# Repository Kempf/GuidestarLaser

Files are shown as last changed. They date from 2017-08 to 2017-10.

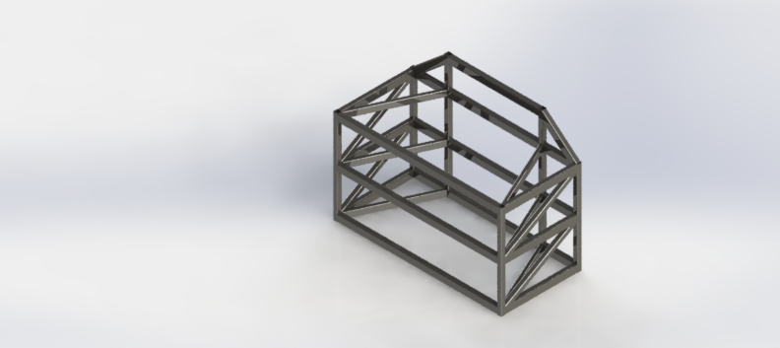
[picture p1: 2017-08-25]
Working_Files/Figures/3_tier_concept_1.JPG

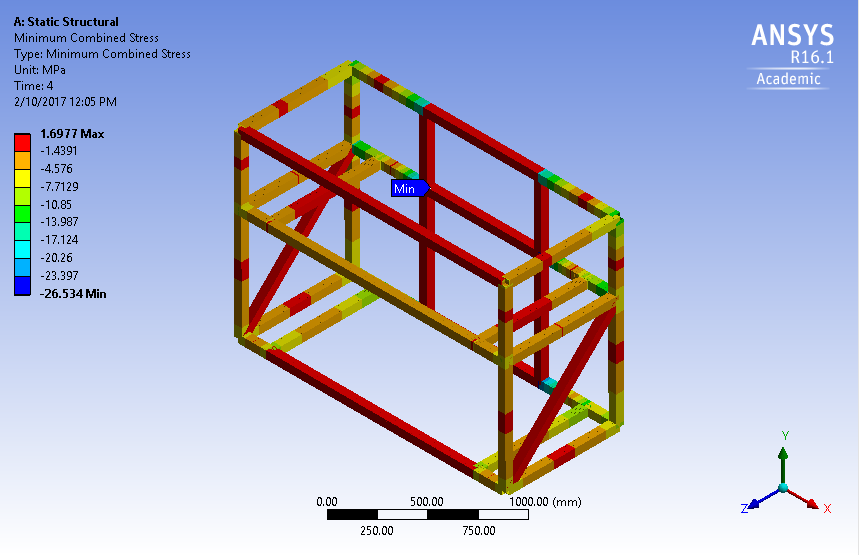
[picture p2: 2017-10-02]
Working_Files/Mechanical_Interface_Preliminary_Design/ansys_analysis/figures/min_comb_stress.PNG

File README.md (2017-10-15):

# Guide Star Laser Project

Repository created on: 04/08/2017

The goal of the project is to develop a **preliminary design** for mounting the EOS and ANU guide star lasers on the EOS 1.8m telescope at Mt. Stromlo, including a document detailing the full requirements and specifications with the highest level of precision available 
with the information avaiable for the most likely configurations, and CAD models supporting this information.

The telescope is used for **laser-tracking satellites** and **space debris**, but its accuracy is limited by the **atmospheric distortions**. A laser guide star (produced by a **guide star laser**, which excites the sodium layer in the atmosphere)
can be used to correct the atmospheric distortions using **adaptive optics** on the telescope. Two such guide star lasers (GSLs) are currently being made for the telescope.

The key components of the mounting are the **mechanical interface** (the support frame and actual physical mounting technique, including vibration limiting techniques), the **environmental
considerations** such as air quality and humidity limitations, the **electrical and communication** limitations involved with mounting the lasers and connecting them to the control system,
due to limitations in the available connections within the dome, and the **logistical concerns**, due to the difficulty of mounting a large laser into the dome, which is a confined space. 

The team works on this **weekly** on Fridays 9-5 in a shared space at AITC, Mt Stromlo, enabling strong communication within the team, as well as ease of communications with our client and stakeholders. 
Additional work is completed externally, including meetings for feedback reviews and individual work.

project diagram

(Diagram supplied by EOS)

## Team

| Member Name  	| UID | Responsibilities | Skills 	|
|---	|---	|---	|---|
| Alex Dalton  	|  u5889439 | Project Manager, Mech., CAD |Mechanical/Materials Eng, CAD, Project management
| Brian Ma  	|  u5893274 | Electrical |Power electronics/system Eng, MATLAB, Python, embeded C, microprocessor, wirless communication |
| Chris Leow  	|  u5827718 | Minutes, Design Report |Mechanical/Materials Eng, Fluid Mechanics & Heat Transfer, Project management, secretary experience, technical dawing|
| Paul Apelt  	|  u5568225 | Project requirements |Electronic/Mechatronic, MATLAB, Python |
| Steve Lonergan|  u5349877 | Point of Contact, vibration|Electronic/Mechatronic, MATLAB, Project Management|
| Wenjie Mu  	|  u5354143 | Cooling |Mechatronics/Renewable Systems, MATLAB, Hardware Programming |
*"Responsibilities" are the areas for which the team member is the key source of knowledge.
All team members will contribute to related project tasks as required.

## Information for Auditors

The readmes of the higher level directories detail their contents, to aid in finding the relevant files and information. 

In this audit cycle, we have completed the seecond, and majority of the third phase of our project - this has been completion of concept designs for each of the Environmental, Mechanical, and Electrical work packages. This is shown in 
the reports for each section. We have also further updated the system subsystem requirements to reflect the current state of the project. The handover document, as well as the Concept Design Report, are still to be completed, however these are 
summaries of the work package reports.

Significant additional information became available in this time period due to the contract on the laser being arranged, however there are still gaps in this information which will be tasked to the next project team.

To get an understanding of what the most relevant files are for this (2nd) audit, go to:
[Current Status Directory](https://gitlab.cecs.anu.edu.au/u5568225/GuidestarLaser/tree/master/Current_Status) 
and read the **Weekly_And_Audit_Summaries.pdf** file.  This will guide you through where to go, what to look at, and what they are.

## Contents

* **Client Communications**: contains all one-way communication with the client, 
including **emails** and **information provided**. This does not include the transcripts
of meetings held with the client present, which are instead in the 
"Meeting Minutes".

* **Current Status**: contains key documents showing the current status of the
project; the **calendar** shows key upcoming dates, while the currrent work 
section contains a statement of the things that need to be done and areas of
priority up until the next update. Periodically updated as work progresses.
	
* **Meeting Minutes**: contains **minutes** for group meetings,
tutorials, and client meetings.

* **Previous Team Work**: this directory effectively contains the entirety of the
**previous group's repository** on this project, to be used as reference material
for our continuation of their work. The readme file within this repository
contains the contents and breakdown, in order to avoid oversaturating this file.

* **Project Deliverables**: contains final project outputs, concept and subsystem design reports.

* **Working Files**: this directory contains **techincal project documents**, **requirements** and
deliverables. Confidential documents are not available for viewing, however
a brief description is provided in the readme file.

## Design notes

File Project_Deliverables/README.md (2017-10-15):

## Project Deliverables
Final project outputs

### Directories
*   **CAD**: contains solidworks laser enclosure models.
### Files

*	`ProForma_Ver005.pdf`:	[Overleaf](https://www.overleaf.com/10595988ydvxrwtmksfk) Initial project document, giving project outline, status, and risks associated with it.
*	`CoDR.pdf`:	Final summary document that summarieses all work packages, and the project as a whole. Overleaf: https://www.overleaf.com/read/mfkmyykbmsgq
*	`Electrical_Subsystem_Design.pdf`:	Design report of the electrical system. Overleaf: https://www.overleaf.com/read/cgpdrtmwvhnf
*	`Environmental_Subsystem_Design.pdf`:	Design report of the environmental system. Overleaf: https://www.overleaf.com/read/kgrchxybbxrv
*	`Mechanical_Subsystem_Design.pdf`:	Design report of the mechanical system. Overleaf: https://www.overleaf.com/read/rwhvbqhndjvv
*   `Updated_System_Subsystem_Specifications_Verxxx`: contains system requirements.
*   `Handover_Document.pdf`: contains information for the next team.

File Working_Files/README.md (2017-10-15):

## Working Files
This folder is the general folder for storage of files and work completed.

### Directories
*	**Audit_Feedback_Actions**: Actions and decisions made in response to client and shadow feedback.
*	**Cable_Routing**: diagrams with measurments of cable trays.
*	**Concept_Design_Report_Documentation**: contains the concept design report.
*	**Dome_Photos**: photos of the telescope space.
*	**Electrical_Interface_Preliminary_Design**: electrical schematics and considerations.
*	**Environmental_Interface_Preliminary_Design**: environmental schematics and considerations.
*	**Figures**: generic figures for reports, diagrams, etc.
*	**Liquid Cooling**:	Cooling schematics folder
*	**Mechanical_Interface_Preliminary_Design**: CAD frame design and ANSYS analysis
*	**Outdated**: contains old versions of documents.
*	**Poster**:	Contains the poster for submission

### Files
*	`Work_Ethic_Agreement.docx`:	This file details the expectations that the group has for each group member, regarding weekly workload and work locations, as well as communications standards, and expectations in the event of absences.
	
*	`ProForma_Verxxx.pdf`:		Details the scope of the project, the project objectives and deliverables, as well as a basic scheduling, project breakdown, and risk analysis. This is intended as an update of the previous teams work, as well as an overview of the project. Overleaf: https://www.overleaf.com/10595988ydvxrwtmksfk#/39637919/
	
*	`Clean_System_Subsystem_Requirements_Updated_Ver001`:      Updated System Requirements Document. Cleaned of old requirements. Overleaf:  https://www.overleaf.com/10750310ksnspqwxvswk  Work-In-Progress

*	`Trace_System_Subsystem_Requirements_Updated_Ver001`:      Updated System Requirements Document. Build off System_Subsystem_Requirements. Overleaf:  https://www.overleaf.com/11432648vkzvdvqvqdgp  Work-In-Progress

*	`System_Subsystem_Requirements.pdf`:     System Subsystem Specifications - from previous team work

*	`DRAFT_laser_mounting_concepts.pdf`:     Details the different scenarios for the laser mounting order / structure

*	[Conflict resolution](https://docs.google.com/document/d/17XI3bLXP9oA0JVAiUGPcVCycXSnSJn45uxt__P4Jb6M/edit?usp=sharing) -  TODO list to resolve requirement conflicts

*	[Vibration Overview](https://docs.google.com/document/d/1Qyyc3R13YdVeQmGfrSNuc1xS96W7sWySw377b-xw7Hk/edit?usp=sharing) - google doc with information on vibration-sensitive components.

*	[Concept Design Report](https://www.overleaf.com/10956191yqmndhrgpfbn) (overleaf draft)

*	[Electrical Subsystem Design](https://www.overleaf.com/11322851qgcphdpmpbkq) (overleaf)

*	[Environmental Subsystem Design](https://www.overleaf.com/11303618bsgxdkttkfjt) (overleaf)

*	[Mechanical Subsystem Design](https://www.overleaf.com/11387889gsdtxpvjycmr) (overleaf)

*	[Audit Presentation](https://docs.google.com/presentation/d/1nnK7gd8TsdCD4ll5tbwI-uf9ibSjlfKKlfrT97bMyMw/edit?usp=sharing) - on google docs

*	[Client & JW meeting presentation](https://docs.google.com/presentation/d/1jMZxCukPx--ZBQRgz2PcXL9bV2g-9_YzMjzdAsr_qN8/edit?usp=sharing) - google docs draft

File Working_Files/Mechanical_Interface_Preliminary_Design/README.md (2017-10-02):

### Directories
*	**ansys_analysis**: files relating to ANSYS analysis of the mounting frame
*	**solidworks_models**: files relating to SolidWorks modelling of the mounting frame

### Files
*	**Breadboard_DataSheet.pdf**: scanned copy of the Carbon Figure breadboard specifications
*	**README.md**: this file

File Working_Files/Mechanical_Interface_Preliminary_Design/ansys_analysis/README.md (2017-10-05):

### Directories
*	**figures**: ANSYS screenshots to present in subsystem report

### Files
*	**1D_frame_model.agdb**: ANSYS geometry file for 1D frame model
*   **frame_analysis.mechdat**: ANSYS analysis file
*   **material_data.xml**: Material constants for isotropic approximation of carbon fibre/epoxy composite
*	**README.md**: this file

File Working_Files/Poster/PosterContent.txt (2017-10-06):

Project Summary

A Guide Star Laser (GSL) creates an artificial star in the atmosphere known as a Laser Guide Star (LGS), which enables the measurement of light distortion caused by atmospheric turbulance. Adaptive Optics (AO) systems use these measurements to correct for this distortion and improve imaging quality.
The ANU and Electric-Optic Systems (EOS) are currently designing two GSL systems for Space Debris Tracking and Pushing. The objective of this project was to develop the concept design for the system interface with the 1.8m telescope at Mount Stromlo. This is the second phase of this student led project, with the first phase involving the development of a comprehensive requirements document.

Laser Enclosure
[IMAGE Frame]
A frame was designed to mount the GSL Laser Heads to the 1.8m telescope. The frame accomodates two optical breadboards and is constructed from DragonPlate Carbon Fibre/Epoxy components, steel inserts and various fasteners.
Insulation panelling and radiators are used to ensure the enclosure temperature remains within tolerable limits. A closed air circulation and filtration system is used to keep air quality to the required ISO 7 Standard. 

ANU Aux EC
The ANU laser power draw requirements are still unknown as the vendor agreement was recently signed, but it will require less than 800W of cooling and 1 CAN bus to monitor and control the status. The electrical cabinet will require one main power socket and the possibility of an additional cooler and power socket that has yet to be finalised. 

[IMAGE]
The ANU GSL has vibrationally sensitive components that will be dampened, while the EOS GSL will be require further analysis as coolers and fans may disrupt instrumentation alignment on breadboards. 

EOS Oscillators
The EOS Oscillators are sensitive to vibrations and have been relocated to an external clean room. This requires additional wiring to connect the oscillators to the observation level. 

EOS Aux EC
The EOS GSL requires a standard power socket to provide 2.4kW of power single phase controlled using a CAN bus and an ethernet cable for maintenance. The heat exchangers will require 3 main power sockets and 1 for the chiller that will provide approximately 400W of water cooling. The EOS GSL requires a minimum of 10 power cables that enter the breadboard for coolers, heat exchangers and providing power.

Summary
Review and additional development of the interface requirements was undertaken by the team. Conceptual designs for the various subsystems were then developed. The designs and recommendations were provided to the client in a Concept Design Report and Subsystem Design Reports. The next phase of the project will involve the development of detailed designs. The team will produce a handover document that introduces the new team to project and outlines the recommended next steps.

Acknowledgements
James Webb, Mark Blundell, Celine d’Orgeville, Jordan Davis, Gerrard Kennedy and all others at ANU, AITC and EOS who made this project possible.

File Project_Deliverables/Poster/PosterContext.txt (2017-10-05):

Project Summary
This iteration of the project utilises design requirements from the previous group to synthesis a concept design for a system interface that is capable of accommodating two Guide Star Laser (GSL) solutions for a 1.8m telescope. A GSL creates an artificial star known as a Laser Guide Star (LGS) in the atmosphere that enables the measurement of phase distortions caused by atmospheric turbulence. Thus, an Adaptive Optics (AO) system for satellite Imaging (AOI) and space debris Tracking and Pushing is enabled (AOTP). 
Laser Enclosure
[IMAGE Frame]
The quasi-isotropic carbon fibre/epoxy composite frame is designed to accommodate two breadboards using square hollow section members and prefabricated gusset plates from DragonPlate an American manufacturer. By utilising carbon fibre, it reduces the mass of the structure while also the Coefficient of Thermal Expansion (CTE) in comparison to steel, that would otherwise affect the alignment of instrumentation on the breadboards during extreme temperature changes the telescope is exposed to. Removable opaque panelling made of ?? will be placed on the sides of the frame to adhere to laser safety, while also reducing dust particulates settling on the breadboards. 
ANU Aux EC

Logistics
There is not enough information 
Wiring (vibration + environment)
Air quality within the enclosure is required to be ISO 7 standard, and temperature must be regulated to enable the temperature range to remain between 5℃-30℃. A closed air circulating system to filter air and cool enclosure air. 
[IMAGE]
The ANU GSL has vibrationally sensitive components that will be dampened, while the EOS GSL will be require further analysis as coolers and fans may disrupt instrumentation alignment on breadboards. 
EOS Oscillators
The Electro-Optic Systems (EOS) Oscillators and vibrationally sensitive and therefore have been relocated to the clean room, resulting in the need for wiring to run from the clean room to the observation deck in the telescope. 
EOS Aux EC

Acknowledgements
James Webb, Mark Blundell, Celine d’Orgeville, Jordan Davis

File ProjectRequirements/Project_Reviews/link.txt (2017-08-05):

https://drive.google.com/open?id=0B3XSOOtE5u1ubnV5ZG04RnpfVTQ
Link to google drive hosting the powerpoints

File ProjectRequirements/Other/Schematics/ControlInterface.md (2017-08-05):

%!PS-Adobe-3.0 EPSF-3.0
%%Creator: Mayura Draw, Version 4.5
%%Title: ControlInterface.md
%%CreationDate: Wed Apr 05 11:33:21 2017
%%BoundingBox: 20 26 591 784
%%DocumentFonts: ArialMT
%%Orientation: Landscape
%%EndComments
%%BeginProlog
%%BeginResource: procset MayuraDraw_ops
%%Version: 4.5
%%Copyright: (c) 1993-2003 Mayura Software
/PDXDict 100 dict def
PDXDict begin
% width height matrix proc key cache
% definepattern -\> font
/definepattern { %def
  7 dict begin
    /FontDict 9 dict def
    FontDict begin
      /cache exch def
      /key exch def
      /proc exch cvx def
      /mtx exch matrix invertmatrix def
      /height exch def
      /width exch def
      /ctm matrix currentmatrix def
      /ptm matrix identmatrix def
      /str
      (xxxxxxxxxxxxxxxxxxxxxxxxxxxxxxxx)
      def
    end
    /FontBBox [ %def
      0 0 FontDict /width get
      FontDict /height get
    ] def
    /FontMatrix FontDict /mtx get def
    /Encoding StandardEncoding def
    /FontType 3 def
    /BuildChar { %def
      pop begin
      FontDict begin
        width 0 cache { %ifelse
          0 0 width height setcachedevice
        }{ %else
          setcharwidth
        } ifelse
        0 0 moveto width 0 lineto
        width height lineto 0 height lineto
        closepath clip newpath
        gsave proc grestore
      end end
    } def
    FontDict /key get currentdict definefont
  end
} bind def

% dict patternpath -
% dict matrix patternpath -
/patternpath { %def
  dup type /dicttype eq { %ifelse
    begin FontDict /ctm get setmatrix
  }{ %else
    exch begin FontDict /ctm get setmatrix
    concat
  } ifelse
  currentdict setfont
  FontDict begin
    FontMatrix concat
    width 0 dtransform
    round width div exch round width div exch
    0 height dtransform
    round height div exch
    round height div exch
    0 0 transform round exch round exch
    ptm astore setmatrix

    pathbbox
    height div ceiling height mul 4 1 roll
    width div ceiling width mul 4 1 roll
    height div floor height mul 4 1 roll
    width div floor width mul 4 1 roll

    2 index sub height div ceiling cvi exch
    3 index sub width div ceiling cvi exch
    4 2 roll moveto

    FontMatrix ptm invertmatrix pop
    { %repeat
      gsave
        ptm concat
        dup str length idiv { %repeat
          str show
        } repeat
        dup str length mod str exch
        0 exch getinterval show
      grestore
      0 height rmoveto
    } repeat
    pop
  end end
} bind def

% dict patternfill -
% dict matrix patternfill -
/patternfill { %def
  gsave
    eoclip patternpath
  grestore
  newpath
} bind def

/img { %def
  gsave
  /imgh exch def
  /imgw exch def
  concat
  imgw imgh 8
  [imgw 0 0 imgh neg 0 imgh]
  /colorstr 768 string def
  /colorimage where {
    pop
    { currentfile colorstr readhexstring pop }
    false 3 colorimage
  }{
    /graystr 256 string def
    {
      currentfile colorstr readhexstring pop
      length 3 idiv
      dup 1 sub 0 1 3 -1 roll
      {
        graystr exch
        colorstr 1 index 3 mul get 30 mul
        colorstr 2 index 3 mul 1 add get 59 mul
        colorstr 3 index 3 mul 2 add get 11 mul
        add add 100 idiv
        put
      } for
      graystr 0 3 -1 roll getinterval
    } image
  } ifelse
  grestore
} bind def

/arrowhead {
  gsave
    [] 0 setdash
    strokeC strokeM strokeY strokeK setcmykcolor
    2 copy moveto
    4 2 roll exch 4 -1 roll exch
    sub 3 1 roll sub
    exch atan rotate dup scale
    arrowtype
    dup 0 eq {
      -1 2 rlineto 7 -2 rlineto -7 -2 rlineto
      closepath fill
    } if
    dup 1 eq {
      0 3 rlineto 9 -3 rlineto -9 -3 rlineto
      closepath fill
    } if
    dup 2 eq {
      -6 -6 rmoveto 6 6 rlineto -6 6 rlineto
      -1.4142 -1.4142 rlineto 4.5858 -4.5858 rlineto
      -4.5858 -4.5858 rlineto closepath fill
    } if
    dup 3 eq {
      -6 0 rmoveto -1 2 rlineto 7 -2 rlineto -7 -2 rlineto
      closepath fill
    } if
    dup 4 eq {
      -9 0 rmoveto 0 3 rlineto 9 -3 rlineto -9 -3 rlineto
      closepath fill
    } if
    dup 5 eq {
      currentpoint newpath 3 0 360 arc
      closepath fill
    } if
    dup 6 eq {
      2.5 2.5 rmoveto 0 -5 rlineto -5 0 rlineto 0 5 rlineto
      closepath fill
    } if
    pop
  grestore
} bind def

/setcmykcolor where { %ifelse
  pop
}{ %else
  /setcmykcolor {
     /black exch def /yellow exch def
     /magenta exch def /cyan exch def
     cyan black add dup 1 gt { pop 1 } if 1 exch sub
     magenta black add dup 1 gt { pop 1 } if 1 exch sub
     yellow black add dup 1 gt { pop 1 } if 1 exch sub
     setrgbcolor
  } bind def
} ifelse

/RE { %def
  findfont begin
  currentdict dup length dict begin
    { %forall
      1 index /FID ne { def } { pop pop } ifelse
    } forall
    /FontName exch def dup length 0 ne { %if
      /Encoding Encoding 256 array copy def
      0 exch { %forall
        dup type /nametype eq { %ifelse
          Encoding 2 index 2 index put
          pop 1 add
        }{ %else
          exch pop
        } ifelse
      } forall
    } if pop
  currentdict dup end end
  /FontName get exch definefont pop
} bind def

/spacecount { %def
  0 exch
  ( ) { %loop
    search { %ifelse
      pop 3 -1 roll 1 add 3 1 roll
    }{ pop exit } ifelse
  } loop
} bind def

/WinAnsiEncoding [
  39/quotesingle 96/grave 130/quotesinglbase/florin/quotedblbase
  /ellipsis/dagger/daggerdbl/circumflex/perthousand
  /Scaron/guilsinglleft/OE 145/quoteleft/quoteright
  /quotedblleft/quotedblright/bullet/endash/emdash
  /tilde/trademark/scaron/guilsinglright/oe/dotlessi
  159/Ydieresis 164/currency 166/brokenbar 168/dieresis/copyright
  /ordfeminine 172/logicalnot 174/registered/macron/ring
  177/plusminus/twosuperior/threesuperior/acute/mu
  183/periodcentered/cedilla/onesuperior/ordmasculine
  188/onequarter/onehalf/threequarters 192/Agrave/Aacute
  /Acircumflex/Atilde/Adieresis/Aring/AE/Ccedilla
  /Egrave/Eacute/Ecircumflex/Edieresis/Igrave/Iacute
  /Icircumflex/Idieresis/Eth/Ntilde/Ograve/Oacute
  /Ocircumflex/Otilde/Odieresis/multiply/Oslash
  /Ugrave/Uacute/Ucircumflex/Udieresis/Yacute/Thorn
  /germandbls/agrave/aacute/acircumflex/atilde/adieresis
  /aring/ae/ccedilla/egrave/eacute/ecircumflex
  /edieresis/igrave/iacute/icircumflex/idieresis
  /eth/ntilde/ograve/oacute/ocircumflex/otilde
  /odieresis/divide/oslash/ugrave/uacute/ucircumflex
  /udieresis/yacute/thorn/ydieresis
] def

/SymbolEncoding [
  32/space/exclam/universal/numbersign/existential/percent
  /ampersand/suchthat/parenleft/parenright/asteriskmath/plus
  /comma/minus/period/slash/zero/one/two/three/four/five/six
  /seven/eight/nine/colon/semicolon/less/equal/greater/question
  /congruent/Alpha/Beta/Chi/Delta/Epsilon/Phi/Gamma/Eta/Iota
  /theta1/Kappa/Lambda/Mu/Nu/Omicron/Pi/Theta/Rho/Sigma/Tau
  /Upsilon/sigma1/Omega/Xi/Psi/Zeta/bracketleft/therefore
  /bracketright/perpendicular/underscore/radicalex/alpha
  /beta/chi/delta/epsilon/phi/gamma/eta/iota/phi1/kappa/lambda
  /mu/nu/omicron/pi/theta/rho/sigma/tau/upsilon/omega1/omega
  /xi/psi/zeta/braceleft/bar/braceright/similar
  161/Upsilon1/minute/lessequal/fraction/infinity/florin/club
  /diamond/heart/spade/arrowboth/arrowleft/arrowup/arrowright
  /arrowdown/degree/plusminus/second/greaterequal/multiply
  /proportional/partialdiff/bullet/divide/notequal/equivalence
  /approxequal/ellipsis/arrowvertex/arrowhorizex/carriagereturn
  /aleph/Ifraktur/Rfraktur/weierstrass/circlemultiply
  /circleplus/emptyset/intersection/union/propersuperset
  /reflexsuperset/notsubset/propersubset/reflexsubset/element
  /notelement/angle/gradient/registerserif/copyrightserif
  /trademarkserif/product/radical/dotmath/logicalnot/logicaland
  /logicalor/arrowdblboth/arrowdblleft/arrowdblup/arrowdblright
  /arrowdbldown/lozenge/angleleft/registersans/copyrightsans
  /trademarksans/summation/parenlefttp/parenleftex/parenleftbt
  /bracketlefttp/bracketleftex/bracketleftbt/bracelefttp
  /braceleftmid/braceleftbt/braceex
  241/angleright/integral/integraltp/integralex/integralbt
  /parenrighttp/parenrightex/parenrightbt/bracketrighttp
  /bracketrightex/bracketrightbt/bracerighttp/bracerightmid
  /bracerightbt
] def

/patarray [
/leftdiagonal /rightdiagonal /crossdiagonal /horizontal
/vertical /crosshatch /fishscale /wave /brick
] def
/arrowtype 0 def
/fillC 0 def /fillM 0 def /fillY 0 def /fillK 0 def
/strokeC 0 def /strokeM 0 def /strokeY 0 def /strokeK 1 def
/pattern -1 def
/mat matrix def
/mat2 matrix def
/nesting 0 def
/deferred /N def
/c /curveto load def
/c2 { pop pop c } bind def
/C /curveto load def
/C2 { pop pop C } bind def
/e { gsave concat 0 0 moveto } bind def
/F {
  nesting 0 eq { %ifelse
    pattern -1 eq { %ifelse
      fillC fillM fillY fillK setcmykcolor eofill
    }{ %else
      gsave fillC fillM fillY fillK setcmykcolor eofill grestore
      0 0 0 1 setcmykcolor
      patarray pattern get findfont patternfill
    } ifelse
  }{ %else
    /deferred /F def
  } ifelse
} bind def
/f { closepath F } bind def
/K { /strokeK exch def /strokeY exch def
     /strokeM exch def /strokeC exch def } bind def
/k { /fillK exch def /fillY exch def
     /fillM exch def /fillC exch def } bind def
/opc { pop } bind def
/Opc { pop } bind def
/L /lineto load def
/L2 { pop pop L } bind def
/m /moveto load def
/m2 { pop pop m } bind def
/n /newpath load def
/N {
  nesting 0 eq { %ifelse
    newpath
  }{ %else
    /deferred /N def
  } ifelse
} def
/S {
  nesting 0 eq { %ifelse
    strokeC strokeM strokeY strokeK setcmykcolor stroke
  }{ %else
    /deferred /S def
  } ifelse
} bind def
/s { closepath S } bind def
/Tx { fillC fillM fillY fillK setcmykcolor show
      0 leading neg translate 0 0 moveto } bind def
/T { grestore } bind def
/TX { pop } bind def
/Ts { pop } bind def
/tal { pop } bind def
/tld { pop } bind def
/tbx { pop exch pop sub /jwidth exch def } def
/tpt { %def
  fillC fillM fillY fillK setcmykcolor
  moveto show
} bind def
/tpj { %def
  fillC fillM fillY fillK setcmykcolor
  moveto
  dup stringwidth pop
  3 -1 roll
  exch sub
  1 index spacecount
  dup 0 eq { %ifelse
    pop pop show
  }{ %else
    div 0 8#040 4 -1 roll widthshow
  } ifelse
} bind def
/u {} def
/U {} def
/*u { /nesting nesting 1 add def } def
/*U {
  /nesting nesting 1 sub def
  nesting 0 eq {
    deferred cvx exec
  } if
} def
/w /setlinewidth load def
/d /setdash load def
/B {
  nesting 0 eq { %ifelse
    gsave F grestore S
  }{ %else
    /deferred /B def
  } ifelse
} bind def
/b { closepath B } bind def
/z { /align exch def pop /leading exch def exch findfont
     exch scalefont setfont } bind def
/tfn { exch findfont
     exch scalefont setfont } bind def
/Pat { /pattern exch def } bind def
/cm { 6 array astore concat } bind def
/q { mat2 currentmatrix pop } bind def
/Q { mat2 setmatrix } bind def
/Ah {
  pop /arrowtype exch def
  currentlinewidth 5 1 roll arrowhead
} bind def
/Arc {
  mat currentmatrix pop
    translate scale 0 0 1 5 -2 roll arc
  mat setmatrix
} bind def
/Arc2 { pop pop Arc } bind def
/Bx {
  mat currentmatrix pop
    concat /y1 exch def /x1 exch def /y2 exch def /x2 exch def
    x1 y1 moveto x1 y2 lineto x2 y2 lineto x2 y1 lineto
  mat setmatrix
} bind def
/Rr {
  mat currentmatrix pop
    concat /yrad exch def /xrad exch def
    2 copy gt { exch } if /x2 exch def /x1 exch def
    2 copy gt { exch } if /y2 exch def /y1 exch def
    x1 xrad add y2 moveto
    matrix currentmatrix x1 xrad add y2 yrad sub translate xrad yrad scale
    0 0 1 90 -180 arc setmatrix
    matrix currentmatrix x1 xrad add y1 yrad add translate xrad yrad scale
    0 0 1 180 270 arc setmatrix
    matrix currentmatrix x2 xrad sub y1 yrad add translate xrad yrad scale
    0 0 1 270 0 arc setmatrix
    matrix currentmatrix x2 xrad sub y2 yrad sub translate xrad yrad scale
    0 0 1 0 90 arc setmatrix
    closepath
  mat setmatrix
} bind def
/Ov {
  mat currentmatrix pop
    concat translate scale 1 0 moveto 0 0 1 0 360 arc closepath
  mat setmatrix
} bind def
end
%%EndResource
%%EndProlog
%%BeginSetup
%PDX g 3 3 0 0
%%IncludeFont: ArialMT
PDXDict begin
%%EndSetup
%%Page: 1 1
%%BeginPageSetup
/_PDX_savepage save def

15 15 [300 72 div 0 0 300 72 div 0 0]
{ %definepattern
  2 setlinecap
  7.5 0 moveto 15 7.5 lineto
  0 7.5 moveto 7.5 15 lineto
  2 setlinewidth stroke
} bind
/rightdiagonal true definepattern pop

15 15 [300 72 div 0 0 300 72 div 0 0]
{ %definepattern
  2 setlinecap
  7.5 0 moveto 0 7.5 lineto
  15 7.5 moveto 7.5 15 lineto
  2 setlinewidth stroke
} bind
/leftdiagonal true definepattern pop

15 15 [300 72 div 0 0 300 72 div 0 0]
{ %definepattern
  2 setlinecap
  0 7.5 moveto 15 7.5 lineto
  2 setlinewidth stroke
} bind
/horizontal true definepattern pop

15 15 [300 72 div 0 0 300 72 div 0 0]
{ %definepattern
  2 setlinecap
  7.5 0 moveto 7.5 15 lineto
  2 setlinewidth stroke
} bind
/vertical true definepattern pop

15 15 [300 72 div 0 0 300 72 div 0 0]
{ %definepattern
  2 setlinecap
  0 7.5 moveto 15 7.5 lineto
  7.5 0 moveto 7.5 15 lineto
  2 setlinewidth stroke
} bind
/crosshatch true definepattern pop

30 30 [300 72 div 0 0 300 72 div 0 0]
{ %definepattern
  2 setlinecap
  0 7.5 moveto 30 7.5 lineto
  0 22.5 moveto 30 22.5 lineto
  7.5 0 moveto 7.5 7.5 lineto
  7.5 22.5 moveto 7.5 30 lineto
  22.5 7.5 moveto 22.5 22.5 lineto
  1 setlinewidth stroke
} bind
/brick true definepattern pop

30 30 [300 72 div 0 0 300 72 div 0 0]
{ %definepattern
  2 2 scale
  2 setlinecap
  7.5 0 moveto 15 7.5 lineto
  0 7.5 moveto 7.5 15 lineto
  7.5 0 moveto 0 7.5 lineto
  15 7.5 moveto 7.5 15 lineto
  0.5 setlinewidth stroke
} bind
/crossdiagonal true definepattern pop

30 30 [300 72 div 0 0 300 72 div 0 0]
{ %definepattern
  2 2 scale
  1 setlinecap
  0 7.5 moveto 0 15 7.5 270 360 arc
  7.5 15 moveto 15 15 7.5 180 270 arc
  0 7.5 moveto 7.5 7.5 7.5 180 360 arc
  0.5 setlinewidth stroke
} bind
/fishscale true definepattern pop

30 30 [300 72 div 0 0 300 72 div 0 0]
{ %definepattern
  1 setlinecap 0.5 setlinewidth
  7.5 0 10.6 135 45 arcn
  22.5 15 10.6 225 315 arc
  stroke
  7.5 15 10.6 135 45 arcn
  22.5 30 10.6 225 315 arc
  stroke
} bind
/wave true definepattern pop

WinAnsiEncoding /_ArialMT /ArialMT RE

newpath 2 setlinecap 0 setlinejoin 2 setmiterlimit
[] 0 setdash
20 26 moveto 20 784 lineto 591 784 lineto 591 26 lineto closepath clip
newpath
%%EndPageSetup
-1.42109e-016 1 0.811765 0 k
0.5 w
188.933 284.045 30.4574 36.6189 [1 0 0 1 0 0] Bx
b
0.364706 0.686274 -1.42109e-016 0 k
135.767 774.807 33.5247 614.287 [1 0 0 1 0 0] Bx
b
0.796078 0.203922 0.67451 0 k
406.709 769.695 223.695 512.045 [1 0 0 1 -23.71 -0.9483] Bx
b
0.74902 0.431373 -1.42109e-016 0 k
406.709 769.695 223.695 512.045 [1 0 0 1 174.6 -1.46] Bx
b
[0 1 -1 0 224.5 8.206] e
103.049 121.48 103.049 121.48 tbx
0 tal
13 tld
1 1 1 0 k
/_ArialMT 12 tfn
(Telescope & Dome) 103.049 110.62 tpt
T
[0 1 -1 0 726.5 577.7] e
91.8027 649.049 91.8027 649.049 tbx
0 tal
13 tld
/_ArialMT 12 tfn
(ANU GSL) 91.8027 638.189 tpt
T
[0 1 -1 0 857.2 302.7] e
314.691 572.368 314.691 572.368 tbx
0 tal
13 tld
/_ArialMT 12 tfn
(EOS GSL) 314.691 561.508 tpt
T
[0 1 -1 0 1054 98.25] e
512.018 563.166 512.018 563.166 tbx
0 tal
13 tld
/_ArialMT 12 tfn
(Toptica GSL) 512.018 552.306 tpt
T
-1.42109e-016 -1.42109e-016 -1.42109e-016 0 k
293.22 616.332 234.942 526.359 [1 0 0 1 -23.71 -0.9483] Bx
b
293.22 616.332 234.942 526.359 [1 0 0 1 -24.73 138.6] Bx
b
293.22 616.332 234.942 526.359 [1 0 0 1 81.6 0.5853] Bx
b
293.22 616.332 234.942 526.359 [1 0 0 1 78.53 137.6] Bx
b
293.22 616.332 234.942 526.359 [1 0 0 1 175.7 -2.482] Bx
b
293.22 616.332 234.942 526.359 [1 0 0 1 176.7 136.6] Bx
b
293.22 616.332 234.942 526.359 [1 0 0 1 -197.3 -481] Bx
b
293.22 616.332 234.942 526.359 [1 0 0 1 -196.3 -344] Bx
b
[0 1 -1 0 118.8 -2.938] e
66.5426 56.9662 66.5426 56.9662 tbx
0 tal
13 tld
1 1 1 0 k
/_ArialMT 12 tfn
(Telescope) 66.5426 46.1062 tpt
T
[0 1 -1 0 256.3 142.2] e
69.3876 192.58 69.3876 192.58 tbx
0 tal
13 tld
/_ArialMT 12 tfn
(Dome) 69.3876 181.72 tpt
T
[0 1 -1 0 863.2 176.3] e
370.013 537.778 370.013 537.778 tbx
0 tal
13 tld
/_ArialMT 12 tfn
(Thermo-) 370.013 526.918 tpt
(\r) TX
(Scientific) 370.013 513.918 tpt
(\r) TX
(Cooler) 370.013 500.918 tpt
T
[0 1 -1 0 1005 322.3] e
358.633 674.34 358.633 674.34 tbx
0 tal
13 tld
/_ArialMT 12 tfn
(TermoTek ) 358.633 663.48 tpt
(\r) TX
(Cooler) 358.633 650.48 tpt
T
[0 1 -1 0 767.4 276.8] e
263.799 535.881 263.799 535.881 tbx
0 tal
13 tld
/_ArialMT 12 tfn
(Electronics ) 263.799 525.021 tpt
(\r) TX
(Cabinet) 263.799 512.021 tpt
T
[0 1 -1 0 907.8 423.8] e
257.16 675.288 257.16 675.288 tbx
0 tal
13 tld
/_ArialMT 12 tfn
(Laser Head) 257.16 664.428 tpt
T
[0 1 -1 0 961.8 74.83] e
463.9 533.984 463.9 533.984 tbx
0 tal
13 tld
/_ArialMT 12 tfn
(Electronics ) 463.9 523.124 tpt
(\r) TX
(Cabinet) 463.9 510.124 tpt
T
[0 1 -1 0 1109 222.8] e
454.416 676.236 454.416 676.236 tbx
0 tal
13 tld
/_ArialMT 12 tfn
(Laser Head) 454.416 665.376 tpt
T
-1.42109e-016 -1.42109e-016 -1.42109e-016 0 k
574.386 268.709 403.641 44.7982 [1 0 0 1 -0.7647 -8.406] Bx
s
[0 1 -1 0 596.2 -384.7] e
484.413 116.368 484.413 116.368 tbx
0 tal
13 tld
1 1 1 0 k
/_ArialMT 12 tfn
(      EOS OCS) 484.413 105.508 tpt
(\r) TX
(\(OUT OF SCOPE\)) 484.413 92.508 tpt
T
-1.42109e-016 -1.42109e-016 -1.42109e-016 0 k
q
1 0 0 1 0 0 cm
61.2009 138.764 61.2009 134.764 m2
61.2009 178.147 61.2009 182.147 L2
Q
B
q
1 0 0 1 0 0 cm
61.2009 182.147 61.2009 134.764 4 1 Ah
61.2009 134.764 61.2009 182.147 4 2 Ah
Q
[0 1 -1 0 187.8 89.36] e
53.6196 137.923 53.6196 137.923 tbx
0 tal
13 tld
1 1 1 0 k
/_ArialMT 12 tfn
( CAN) 53.6196 127.063 tpt
(\r) TX
(\(1.4.1\)) 53.6196 114.063 tpt
T
-1.42109e-016 -1.42109e-016 -1.42109e-016 0 k
q
1 0 0 1 0 0 cm
193.76 74.1145 189.76 74.1145 m2
399.298 74.1145 403.298 74.1145 L2
Q
B
q
1 0 0 1 0 0 cm
403.298 74.1145 189.76 74.1145 4 1 Ah
189.76 74.1145 403.298 74.1145 4 2 Ah
Q
[0 1 -1 0 337.8 -184.5] e
261.15 76.6416 261.15 76.6416 tbx
0 tal
13 tld
1 1 1 0 k
/_ArialMT 12 tfn
(CAN \(1.4.1\)) 261.15 65.7816 tpt
T
q
1 0 0 1 0 0 cm
296.529 507.929 296.529 511.929 m2
296.529 367.255 L
Q
B
q
1 0 0 1 0 0 cm
296.529 367.255 296.529 511.929 4 1 Ah
Q
q
1 0 0 1 0 0 cm
296.529 367.255 m
451.944 367.886 L
Q
B
q
1 0 0 1 0 0 cm
451.944 367.886 m
451.944 264.486 451.944 260.486 L2
Q
B
q
1 0 0 1 0 0 cm
451.944 367.886 451.944 260.486 4 2 Ah
Q
[0 1 -1 0 670.7 51.14] e
318.641 371.677 318.641 371.677 tbx
0 tal
13 tld
/_ArialMT 12 tfn
(CAN for control) 318.641 360.817 tpt
(\r) TX
(\(2.4.3\)) 318.641 347.817 tpt
T
q
1 0 0 1 0 0 cm
340.753 507.298 340.753 511.298 m2
340.753 380.522 L
Q
B
q
1 0 0 1 0 0 cm
340.753 380.522 340.753 511.298 4 1 Ah
Q
q
1 0 0 1 0 0 cm
340.753 380.522 m
470.897 380.522 L
Q
B
q
1 0 0 1 0 0 cm
470.897 380.522 m
470.897 264.486 470.897 260.486 L2
Q
B
q
1 0 0 1 0 0 cm
470.897 380.522 470.897 260.486 4 2 Ah
Q
[0 1 -1 0 728.9 34.71] e
350.229 384.944 350.229 384.944 tbx
0 tal
13 tld
/_ArialMT 12 tfn
(Ethernet for SSH) 350.229 374.084 tpt
(\r) TX
(\(2.4.2\)) 350.229 361.084 tpt
T
q
1 0 0 1 0 0 cm
501.521 263.854 501.521 259.854 m2
501.521 506.666 501.521 510.666 L2
Q
B
q
1 0 0 1 0 0 cm
501.521 510.666 501.521 259.854 4 1 Ah
501.521 259.854 501.521 510.666 4 2 Ah
Q
q
1 0 0 1 0 0 cm
413.074 264.486 413.074 260.486 m2
413.074 346.406 L
Q
B
q
1 0 0 1 0 0 cm
413.074 346.406 413.074 260.486 4 1 Ah
Q
q
1 0 0 1 0 0 cm
413.074 346.406 m
101.612 346.406 L
Q
B
q
1 0 0 1 0 0 cm
101.612 346.406 m
102.235 609.644 102.244 613.644 L2
Q
B
q
1 0 0 1 0 0 cm
101.612 346.406 102.244 613.644 4 2 Ah
Q
[0 1 -1 0 455.3 238.1] e
111.421 350.829 111.421 350.829 tbx
0 tal
13 tld
/_ArialMT 12 tfn
(CAN according to 1.4.1 + 1.4.4??) 111.421 339.969 tpt
T
[0 1 -1 0 876.1 -187.7] e
498.063 387.471 498.063 387.471 tbx
0 tal
13 tld
/_ArialMT 12 tfn
(CAN according to 1.4.1 + 1.4.4??) 498.063 376.611 tpt
T
%%PageTrailer
_PDX_savepage restore
%%Trailer
end
showpage
%%EOF

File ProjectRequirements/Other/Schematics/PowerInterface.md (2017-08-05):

%!PS-Adobe-3.0 EPSF-3.0
%%Creator: Mayura Draw, Version 4.5
%%Title: PowerInterface.md
%%CreationDate: Wed Apr 05 11:34:47 2017
%%BoundingBox: 20 27 591 784
%%DocumentFonts: ArialMT
%%Orientation: Landscape
%%EndComments
%%BeginProlog
%%BeginResource: procset MayuraDraw_ops
%%Version: 4.5
%%Copyright: (c) 1993-2003 Mayura Software
/PDXDict 100 dict def
PDXDict begin
% width height matrix proc key cache
% definepattern -\> font
/definepattern { %def
  7 dict begin
    /FontDict 9 dict def
    FontDict begin
      /cache exch def
      /key exch def
      /proc exch cvx def
      /mtx exch matrix invertmatrix def
      /height exch def
      /width exch def
      /ctm matrix currentmatrix def
      /ptm matrix identmatrix def
      /str
      (xxxxxxxxxxxxxxxxxxxxxxxxxxxxxxxx)
      def
    end
    /FontBBox [ %def
      0 0 FontDict /width get
      FontDict /height get
    ] def
    /FontMatrix FontDict /mtx get def
    /Encoding StandardEncoding def
    /FontType 3 def
    /BuildChar { %def
      pop begin
      FontDict begin
        width 0 cache { %ifelse
          0 0 width height setcachedevice
        }{ %else
          setcharwidth
        } ifelse
        0 0 moveto width 0 lineto
        width height lineto 0 height lineto
        closepath clip newpath
        gsave proc grestore
      end end
    } def
    FontDict /key get currentdict definefont
  end
} bind def

% dict patternpath -
% dict matrix patternpath -
/patternpath { %def
  dup type /dicttype eq { %ifelse
    begin FontDict /ctm get setmatrix
  }{ %else
    exch begin FontDict /ctm get setmatrix
    concat
  } ifelse
  currentdict setfont
  FontDict begin
    FontMatrix concat
    width 0 dtransform
    round width div exch round width div exch
    0 height dtransform
    round height div exch
    round height div exch
    0 0 transform round exch round exch
    ptm astore setmatrix

    pathbbox
    height div ceiling height mul 4 1 roll
    width div ceiling width mul 4 1 roll
    height div floor height mul 4 1 roll
    width div floor width mul 4 1 roll

    2 index sub height div ceiling cvi exch
    3 index sub width div ceiling cvi exch
    4 2 roll moveto

    FontMatrix ptm invertmatrix pop
    { %repeat
      gsave
        ptm concat
        dup str length idiv { %repeat
          str show
        } repeat
        dup str length mod str exch
        0 exch getinterval show
      grestore
      0 height rmoveto
    } repeat
    pop
  end end
} bind def

% dict patternfill -
% dict matrix patternfill -
/patternfill { %def
  gsave
    eoclip patternpath
  grestore
  newpath
} bind def

/img { %def
  gsave
  /imgh exch def
  /imgw exch def
  concat
  imgw imgh 8
  [imgw 0 0 imgh neg 0 imgh]
  /colorstr 768 string def
  /colorimage where {
    pop
    { currentfile colorstr readhexstring pop }
    false 3 colorimage
  }{
    /graystr 256 string def
    {
      currentfile colorstr readhexstring pop
      length 3 idiv
      dup 1 sub 0 1 3 -1 roll
      {
        graystr exch
        colorstr 1 index 3 mul get 30 mul
        colorstr 2 index 3 mul 1 add get 59 mul
        colorstr 3 index 3 mul 2 add get 11 mul
        add add 100 idiv
        put
      } for
      graystr 0 3 -1 roll getinterval
    } image
  } ifelse
  grestore
} bind def

/arrowhead {
  gsave
    [] 0 setdash
    strokeC strokeM strokeY strokeK setcmykcolor
    2 copy moveto
    4 2 roll exch 4 -1 roll exch
    sub 3 1 roll sub
    exch atan rotate dup scale
    arrowtype
    dup 0 eq {
      -1 2 rlineto 7 -2 rlineto -7 -2 rlineto
      closepath fill
    } if
    dup 1 eq {
      0 3 rlineto 9 -3 rlineto -9 -3 rlineto
      closepath fill
    } if
    dup 2 eq {
      -6 -6 rmoveto 6 6 rlineto -6 6 rlineto
      -1.4142 -1.4142 rlineto 4.5858 -4.5858 rlineto
      -4.5858 -4.5858 rlineto closepath fill
    } if
    dup 3 eq {
      -6 0 rmoveto -1 2 rlineto 7 -2 rlineto -7 -2 rlineto
      closepath fill
    } if
    dup 4 eq {
      -9 0 rmoveto 0 3 rlineto 9 -3 rlineto -9 -3 rlineto
      closepath fill
    } if
    dup 5 eq {
      currentpoint newpath 3 0 360 arc
      closepath fill
    } if
    dup 6 eq {
      2.5 2.5 rmoveto 0 -5 rlineto -5 0 rlineto 0 5 rlineto
      closepath fill
    } if
    pop
  grestore
} bind def

/setcmykcolor where { %ifelse
  pop
}{ %else
  /setcmykcolor {
     /black exch def /yellow exch def
     /magenta exch def /cyan exch def
     cyan black add dup 1 gt { pop 1 } if 1 exch sub
     magenta black add dup 1 gt { pop 1 } if 1 exch sub
     yellow black add dup 1 gt { pop 1 } if 1 exch sub
     setrgbcolor
  } bind def
} ifelse

/RE { %def
  findfont begin
  currentdict dup length dict begin
    { %forall
      1 index /FID ne { def } { pop pop } ifelse
    } forall
    /FontName exch def dup length 0 ne { %if
      /Encoding Encoding 256 array copy def
      0 exch { %forall
        dup type /nametype eq { %ifelse
          Encoding 2 index 2 index put
          pop 1 add
        }{ %else
          exch pop
        } ifelse
      } forall
    } if pop
  currentdict dup end end
  /FontName get exch definefont pop
} bind def

/spacecount { %def
  0 exch
  ( ) { %loop
    search { %ifelse
      pop 3 -1 roll 1 add 3 1 roll
    }{ pop exit } ifelse
  } loop
} bind def

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

15 15 [300 72 div 0 0 300 72 div 0 0]
{ %definepattern
  2 setlinecap
  7.5 0 moveto 15 7.5 lineto
  0 7.5 moveto 7.5 15 lineto
  2 setlinewidth stroke
} bind
/rightdiagonal true definepattern pop

15 15 [300 72 div 0 0 300 72 div 0 0]
{ %definepattern
  2 setlinecap
  7.5 0 moveto 0 7.5 lineto
  15 7.5 moveto 7.5 15 lineto
  2 setlinewidth stroke
} bind
/leftdiagonal true definepattern pop

15 15 [300 72 div 0 0 300 72 div 0 0]
{ %definepattern
  2 setlinecap
  0 7.5 moveto 15 7.5 lineto
  2 setlinewidth stroke
} bind
/horizontal true definepattern pop

15 15 [300 72 div 0 0 300 72 div 0 0]
{ %definepattern
  2 setlinecap
  7.5 0 moveto 7.5 15 lineto
  2 setlinewidth stroke
} bind
/vertical true definepattern pop

15 15 [300 72 div 0 0 300 72 div 0 0]
{ %definepattern
  2 setlinecap
  0 7.5 moveto 15 7.5 lineto
  7.5 0 moveto 7.5 15 lineto
  2 setlinewidth stroke
} bind
/crosshatch true definepattern pop

30 30 [300 72 div 0 0 300 72 div 0 0]
{ %definepattern
  2 setlinecap
  0 7.5 moveto 30 7.5 lineto
  0 22.5 moveto 30 22.5 lineto
  7.5 0 moveto 7.5 7.5 lineto
  7.5 22.5 moveto 7.5 30 lineto
  22.5 7.5 moveto 22.5 22.5 lineto
  1 setlinewidth stroke
} bind
/brick true definepattern pop

30 30 [300 72 div 0 0 300 72 div 0 0]
{ %definepattern
  2 2 scale
  2 setlinecap
  7.5 0 moveto 15 7.5 lineto
  0 7.5 moveto 7.5 15 lineto
  7.5 0 moveto 0 7.5 lineto
  15 7.5 moveto 7.5 15 lineto
  0.5 setlinewidth stroke
} bind
/crossdiagonal true definepattern pop

30 30 [300 72 div 0 0 300 72 div 0 0]
{ %definepattern
  2 2 scale
  1 setlinecap
  0 7.5 moveto 0 15 7.5 270 360 arc
  7.5 15 moveto 15 15 7.5 180 270 arc
  0 7.5 moveto 7.5 7.5 7.5 180 360 arc
  0.5 setlinewidth stroke
} bind
/fishscale true definepattern pop

30 30 [300 72 div 0 0 300 72 div 0 0]
{ %definepattern
  1 setlinecap 0.5 setlinewidth
  7.5 0 10.6 135 45 arcn
  22.5 15 10.6 225 315 arc
  stroke
  7.5 15 10.6 135 45 arcn
  22.5 30 10.6 225 315 arc
  stroke
} bind
/wave true definepattern pop

WinAnsiEncoding /_ArialMT /ArialMT RE

newpath 2 setlinecap 0 setlinejoin 2 setmiterlimit
[] 0 setdash
20 27 moveto 20 784 lineto 591 784 lineto 591 27 lineto closepath clip
newpath
%%EndPageSetup
-1.42109e-016 1 0.811765 0 k
0.5 w
188.933 284.045 30.4574 36.6189 [1 0 0 1 0 0] Bx
b
0.364706 0.686274 -1.42109e-016 0 k
135.767 774.807 33.5247 614.287 [1 0 0 1 0 0] Bx
b
0.796078 0.203922 0.67451 0 k
406.709 769.695 223.695 512.045 [1 0 0 1 -23.71 -0.9483] Bx
b
0.74902 0.431373 -1.42109e-016 0 k
406.709 769.695 223.695 512.045 [1 0 0 1 174.6 -1.46] Bx
b
[0 1 -1 0 224.5 8.206] e
103.049 121.48 103.049 121.48 tbx
0 tal
13 tld
1 1 1 0 k
/_ArialMT 12 tfn
(Telescope & Dome) 103.049 110.62 tpt
T
[0 1 -1 0 726.5 577.7] e
91.8027 649.049 91.8027 649.049 tbx
0 tal
13 tld
/_ArialMT 12 tfn
(ANU GSL) 91.8027 638.189 tpt
T
[0 1 -1 0 857.2 302.7] e
314.691 572.368 314.691 572.368 tbx
0 tal
13 tld
/_ArialMT 12 tfn
(EOS GSL) 314.691 561.508 tpt
T
[0 1 -1 0 1054 98.25] e
512.018 563.166 512.018 563.166 tbx
0 tal
13 tld
/_ArialMT 12 tfn
(Toptica GSL) 512.018 552.306 tpt
T
-1.42109e-016 -1.42109e-016 -1.42109e-016 0 k
293.22 616.332 234.942 526.359 [1 0 0 1 -23.71 -0.9483] Bx
b
293.22 616.332 234.942 526.359 [1 0 0 1 -24.73 138.6] Bx
b
293.22 616.332 234.942 526.359 [1 0 0 1 81.6 0.5853] Bx
b
293.22 616.332 234.942 526.359 [1 0 0 1 78.53 137.6] Bx
b
293.22 616.332 234.942 526.359 [1 0 0 1 175.7 -2.482] Bx
b
293.22 616.332 234.942 526.359 [1 0 0 1 176.7 136.6] Bx
b
293.22 616.332 234.942 526.359 [1 0 0 1 -111.4 -345.1] Bx
b
293.22 616.332 234.942 526.359 [1 0 0 1 -197.3 -481] Bx
b
293.22 616.332 234.942 526.359 [1 0 0 1 -196.3 -344] Bx
b
[0 1 -1 0 335.9 39.74] e
151.894 193.528 151.894 193.528 tbx
0 tal
13 tld
1 1 1 0 k
/_ArialMT 12 tfn
(Power Supply ) 151.894 182.668 tpt
(\r) TX
(\(1.1.12,13,14\)) 151.894 169.668 tpt
T
[0 1 -1 0 118.8 -2.938] e
66.5426 56.9662 66.5426 56.9662 tbx
0 tal
13 tld
/_ArialMT 12 tfn
(Telescope) 66.5426 46.1062 tpt
T
[0 1 -1 0 256.3 142.2] e
69.3876 192.58 69.3876 192.58 tbx
0 tal
13 tld
/_ArialMT 12 tfn
(Dome) 69.3876 181.72 tpt
T
[0 1 -1 0 863.2 176.3] e
370.013 537.778 370.013 537.778 tbx
0 tal
13 tld
/_ArialMT 12 tfn
(Thermo-) 370.013 526.918 tpt
(\r) TX
(Scientific) 370.013 513.918 tpt
(\r) TX
(Cooler) 370.013 500.918 tpt
T
[0 1 -1 0 1005 322.3] e
358.633 674.34 358.633 674.34 tbx
0 tal
13 tld
/_ArialMT 12 tfn
(TermoTek ) 358.633 663.48 tpt
(\r) TX
(Cooler) 358.633 650.48 tpt
T
[0 1 -1 0 767.4 276.8] e
263.799 535.881 263.799 535.881 tbx
0 tal
13 tld
/_ArialMT 12 tfn
(Electronics ) 263.799 525.021 tpt
(\r) TX
(Cabinet) 263.799 512.021 tpt
T
[0 1 -1 0 907.8 423.8] e
257.16 675.288 257.16 675.288 tbx
0 tal
13 tld
/_ArialMT 12 tfn
(Laser Head) 257.16 664.428 tpt
T
[0 1 -1 0 961.8 74.83] e
463.9 533.984 463.9 533.984 tbx
0 tal
13 tld
/_ArialMT 12 tfn
(Electronics ) 463.9 523.124 tpt
(\r) TX
(Cabinet) 463.9 510.124 tpt
T
[0 1 -1 0 1109 222.8] e
454.416 676.236 454.416 676.236 tbx
0 tal
13 tld
/_ArialMT 12 tfn
(Laser Head) 454.416 665.376 tpt
T
-1.42109e-016 -1.42109e-016 -1.42109e-016 0 k
q
1 0 0 1 0 0 cm
130.082 271.292 m
130.082 564.331 L
Q
S
q
1 0 0 1 0 0 cm
130.082 564.331 m
83.6128 564.331 L
Q
S
q
1 0 0 1 0 0 cm
83.6128 564.331 m
83.6128 610.594 83.6128 614.594 L2
Q
S
q
1 0 0 1 0 0 cm
83.6128 564.331 83.6128 614.594 4 2 Ah
Q
q
1 0 0 1 0 0 cm
205.743 713.222 209.743 713.222 m2
140.514 713.222 L
Q
S
q
1 0 0 1 0 0 cm
140.514 713.222 209.743 713.222 4 1 Ah
Q
q
1 0 0 1 0 0 cm
140.514 713.222 m
140.514 272.241 L
Q
S
q
1 0 0 1 0 0 cm
206.691 573.819 210.691 573.815 m2
150.257 573.878 L
Q
S
q
1 0 0 1 0 0 cm
150.257 573.878 210.691 573.815 4 1 Ah
Q
q
1 0 0 1 2.845 0 cm
147.152 573.815 m
147.152 271.292 L
Q
S
q
1 0 0 1 3.793 0 cm
157.584 272.241 m
157.584 492.257 L
Q
S
q
1 0 0 1 0 0 cm
161.591 492.343 m
298.887 492.257 L
Q
S
q
1 0 0 1 0 0 cm
298.887 492.257 m
298.887 714.17 L
Q
S
q
1 0 0 1 0 0 cm
298.887 714.17 m
309.693 714.25 313.693 714.28 L2
Q
S
q
1 0 0 1 0 0 cm
298.887 714.17 313.693 714.28 4 2 Ah
Q
q
1 0 0 1 3.793 0.9483 cm
168.016 271.292 m
168.035 474.21 L
Q
S
q
1 0 0 1 0 0 cm
171.829 475.159 m
343.46 475.187 L
Q
S
q
1 0 0 1 0 0 cm
343.46 475.187 m
343.46 523.346 343.46 527.346 L2
Q
S
q
1 0 0 1 0 0 cm
343.46 475.187 343.46 527.346 4 2 Ah
Q
q
1 0 0 1 0 0 cm
181.547 263.013 m
203.027 263.013 L
Q
S
q
1 0 0 1 0 0 cm
203.027 263.645 m
203.027 456.334 L
Q
S
q
1 0 0 1 0 0 cm
203.027 456.334 m
420.987 456.334 L
Q
S
q
1 0 0 1 0 0 cm
420.987 456.334 m
420.987 519.933 420.987 523.933 L2
Q
S
q
1 0 0 1 0 0 cm
420.987 456.334 420.987 523.933 4 2 Ah
Q
q
1 0 0 1 0 0 cm
181.547 251.009 m
215.663 251.009 L
Q
S
q
1 0 0 1 0 0 cm
215.663 251.009 m
215.663 441.171 L
Q
S
q
1 0 0 1 0 0 cm
215.663 441.171 m
474.056 441.171 L
Q
S
q
1 0 0 1 0 0 cm
474.056 441.171 m
474.056 712.2 L
Q
S
q
1 0 0 1 0 0 cm
474.056 712.2 m
473.633 712.2 469.633 712.2 L2
Q
S
q
1 0 0 1 0 0 cm
474.056 712.2 469.633 712.2 4 2 Ah
Q
[0 1 -1 0 480.6 440.3] e
125.32 396.948 125.32 396.948 tbx
0 tal
13 tld
1 1 1 0 k
/_ArialMT 12 tfn
(??) 125.32 386.088 tpt
T
[0 1 -1 0 516.6 288.1] e
179.652 343.247 179.652 343.247 tbx
0 tal
13 tld
/_ArialMT 12 tfn
(1 \(2.2.5\)) 179.652 332.387 tpt
T
[0 1 -1 0 556.4 291.2] e
194.814 395.052 194.814 395.052 tbx
0 tal
13 tld
/_ArialMT 12 tfn
(1 \(2.2.6\)) 194.814 384.192 tpt
T
[0 1 -1 0 728.2 382.8] e
159.435 577.633 159.435 577.633 tbx
0 tal
13 tld
/_ArialMT 12 tfn
(2+/- 1 \(2.2.4\)) 159.435 566.773 tpt
T
[0 1 -1 0 859.6 553.4] e
150.591 717.254 150.591 717.254 tbx
0 tal
13 tld
/_ArialMT 12 tfn
(1 \(2.2.1\)) 150.591 706.394 tpt
T
[0 1 -1 0 679.1 -21.14] e
413.406 460.756 413.406 460.756 tbx
0 tal
13 tld
/_ArialMT 12 tfn
(1 \(3.2.2\)) 413.406 449.896 tpt
T
[0 1 -1 0 652.4 -25.93] e
467.738 449.384 467.738 449.384 tbx
0 tal
13 tld
/_ArialMT 12 tfn
(??) 467.738 438.524 tpt
T
%%PageTrailer
_PDX_savepage restore
%%Trailer
end
showpage
%%EOF

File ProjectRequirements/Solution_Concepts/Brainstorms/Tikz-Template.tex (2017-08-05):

\PassOptionsToPackage{x11names,rgb,usenames,dvipsnames}{xcolor}
\documentclass[border=10pt]{standalone}
\usepackage{tikz}
\usepackage{amsmath}
\usetikzlibrary{calc,positioning,patterns,fit,intersections,decorations.pathreplacing}

\usepackage{tikz-dimline}
\usepackage{wasysym}

%-------------------------------------------------------------------------------------------------------------------------------------------------------------------------------- Shaded Pattern
% Adapted from the 'patterns' library: enlarged the distance between the lines from 4pt to 10pt
\pgfdeclarepatternformonly{north east lines wide}{\pgfqpoint{-1pt}{-1pt}}{\pgfqpoint{10pt}{10pt}}{\pgfqpoint{9pt}{9pt}}%
{
  \pgfsetlinewidth{0.4pt}
  \pgfpathmoveto{\pgfqpoint{0pt}{0pt}}
  \pgfpathlineto{\pgfqpoint{9.1pt}{9.1pt}}
  \pgfusepath{stroke}
}

%----------------------------------------------------------------------------------------------------------------------------------- Tikz Styles
\makeatletter
\tikzset{%
%--------------- Basic Styles
    rect/.style={inner sep=0pt,outer sep=0pt,align=center,shape=rectangle,draw,thick},
    shaded/.style={pattern=north east lines wide},
    OPSL/.style={dashed,Purple,ultra thick},
    symmetry/.style={dashed,thin},
%--------------- Laser Styles 
    mountingplate/.style={rect,fill=black!05!white,fit={(0,0)(6,9)},label=below:{\bfseries Mounting Plate}},
    toptica/.style={rect,draw=NavyBlue,fit={(0,0)(2,6)}, line width = 1pt,
				label={[align=center]above:{\color{NavyBlue}\bfseries Toptica\\ \color{NavyBlue}\bfseries GSL}}
			},
    ANULaser/.style={rect,dashed,Purple,ultra thick, fit={(0,0)(2.5,1)}, label=center:{\color{Purple}\bfseries ANU GSL}},
    breadboard/.style={rect,shaded,label=below:{\color{Orange!20!Red}\bfseries Breadboard},draw=Orange!20!Red,pattern color=Orange!20!Red},
    EOSbreadboard/.style={rect,shaded, minimum width = 9cm, minimum height = 1cm,
					label=above:{\color{PineGreen}\bfseries EOS Breadboard},
					draw=PineGreen,pattern color=PineGreen}
}
\makeatother

%----------------------------------------------------------------------------------------------------------------------------------- Document Start
\begin{document}

%----------------------------------------------------------------------------------------------------------------------------------- Picture Start
\begin{tikzpicture}[scale=1]

% Coordinates
\coordinate[label=below left:] (O) at (0,0);
\node[mountingplate] (MP) at (O) {};
\node[] at (O) {$\otimes$};
\node[rect, dash dot dot, minimum size = 0.75cm, darkgray, label={[align=center]below:{\footnotesize Beam\\[-0.5ex] \footnotesize  Selector}}] at (O) {};
\node[toptica, above left] at (MP.south east) {};
\node[breadboard,fit={(0,0)(2.5,0.5)},right] (nBB) at (MP.west) {};
\node[ANULaser, above] at (nBB.north) {};

%----------------------------------------------------------------------------------------------------------------------------------- Document/Picture End
\end{tikzpicture}
\end{document}

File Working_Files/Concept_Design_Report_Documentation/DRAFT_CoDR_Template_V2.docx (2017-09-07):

Changes in this document were discussed in Sep_1_Update.pdf and Sep_8_Tutor_Meeting.pdf

# Revision History

Version No. | Author & Date | Approval & Date | Description | Verification

# Contents

# Applicable Documents

Document ID | Source | Title | Version | Date

# Acronyms

# Executive Summary

- Project name
- Stakeholders
- Subsystems

# Introduction

# System Requirements

- Top level performance requirements
- Budgets
  - Heat
  - Electricity
  - Mechanical
  - Mass
- Passive/active systems
  - Frequency of use – calibration frequency
- Risk Assessment of most important subsystems

## Subsystem (structural, vibrational reduction, conceptual, temperature, air quality, cooling systems, interior configuration & logistics, electronics & communications)

- List requirements relevant to the system
- Physical characteristics of the system (values + metric)
- Performance characteristics (values + metrics)
- Functional subsystem diagram
- System architecture diagram
- Performance requirement

Requirement ID – title | Requirement statement | Value + units | Notes
| | | (a)

(a) – xxx
- Error Budget table

Requirement Level | | 1 | 2 | 3 | 4
Subsystem component error
Requirement | Metric | | Value
Total Error | Metric | Value

- Associated risks

## Concept Design

- Written
- CAD + Render
  - Annotated components
  - Dimensions
- Scalability of design
  - Scalability of design components
- Architecture flow chart comparison of multiple design options
- Limitations due to alternate subsystem designs or components

Requirement title | Requirement statement | Optical design | Derived mechanical design requirements

- Issues relevant to subsystem
- Error accumulation calculation

Subsystem | Value (Error percentile)

- External Interfaces
  - External system requirements
- Operation modes if multiple
- Prototyping
- Testing
  - Simulation tools
  - Analysis
    - Tables + plots
    - Noise + error analysis
  - Heat map diagrams
    - Description of colours
  - Calculations (if any)
  - Simulation parameters table

Variable | Value

  - Baseline assumptions table

Parameter | Metric + Value | Notes

  - CAD models
  - Simulation maps
  - Predicted values on simulation
  - Control Systems diagram
    - Block diagram
    - High level block diagram
    - Detailed
    - Recommendations to design
- Maintenance
- Summary and conclusion

# Risk Management

# References

- IEEE referencing

CoDR Template

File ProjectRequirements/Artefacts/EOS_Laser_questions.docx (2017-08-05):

- Fill out table in Design requirements document
- Are there any CAD files of the laser?
- What are the interface requirements?
  - Optical
  - Electrical
  - Data/Control
  - Thermal (i.e coolant)
- Mounting considerations
  - Attachment points
  - Vibration
  - Optical adjustments - already in BTO?
  - Compatibility with other laser
- Does it need to be mounted in a certain orientation
- Thermal control
  - How is it cooled?
  - Are there sections can’t be covered? i.e air vents
  - Breadboard spacing
  - Is thermal expansion likely to be an issue
  - Maximal heat load
- Safety aspects
  - Laser leakage
  - Interference
  - Fire contingency

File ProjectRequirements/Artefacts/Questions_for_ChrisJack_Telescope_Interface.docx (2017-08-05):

Questions for Chris

1. How many ethernet ports are available at the telescope dome?
  - 4 spare, full connection, Jack Gray (network traffic)
  - Optical network, general purpose network
2. What are the communication protocols that need to be used by ethernet cable?
  - Standard, separate switch
3. Do you integrate third party control software or allow it to run separately?
  - Alex Pollard, libraries/dlls, realtime control system, special server
  - Sockets, waste of time to make it look like a CAN device
  - If operations can be done manually, automation vs manual operation, physical vs remotely. Prefer remote automation - GUI remote desktop manually. Observatory control system: Guide Star Laser Server, open a TCP socket with laser, interface control document, buy best tech for the right price, software is an afterthought, have to deal with flaky controls, knock on effects of bad design
  - Version of server framework (control system library C++), ideally get as close to hardware as possible, ASCOM is horriffic
  - Engineering layer, GUI
4. Are there any CAN ports/hubs currently in the dome, or being planned?
  - Can, small data amounts
  - Put a separate bus in, through an ethernet interface
  - James will be CAN, connected to an ethernet interface
  - BeagleBone -> CAN bus
  - Can is written in C
5. What are the CAN ports being used for?
  - DML, James Webb will develop it, it will appear in that list as a device
6. What collaboration is there between ANU/EOS/Telescope? What are the plans?
  - Ask Jack
7. Is there any weather data available?
  - Possibly, ask Alex Pollard/Patrick, weather station with data generally available
  - Average, current temp, humidity, dew point calculation - in Dome
  - Telescope truss, the metal temperature, mirror temp, air temp, not as accurate, not calibrated
  - Outside: MET station
  - OCS server in the device browser, can get this data live
  - Too hot? Want the telescope column of air to be the same as the atmosphere
8. What space is available for routing internal cables between floors, and depositing electronics cabinets?
  - James, Jack
  - Tray on each column
  - Cable wrap for things outside the building to get it onto the rotating platform
  - Most of the cables are being damaged from use, like a garden hose, pigtails
  - Originally CAT5 from front racks in square tube through ceiling, inside wall, up pier, through wrap
  - Installed later: fibre cables, used for high speed cameras
  - Not many ports, can we add a switch? Probably the wired ones, but not fibre as it is tricky with virtual LANs
9. What are the requirements to interface with the observatory control systems?
  - Preferences: easiest, pov of installing new HW, CAN is clearly defined, tools exist to describe to call pieces of data (laser status), translate into state messages, end with a list of new commands and data available to entire system
  - Tried ethernet before, have to define API, always different, HW+SW of buggering around with protocols. They have to write software to match supplied drivers.
  - Use GigaVision protocol for cameras, CameraLink interface, have developed an interface
  - Place the electronics cabinet on the middle or ground floor on the rotating section
  - Can can do a lot, measure/output analog digital voltages
10. Is there scope to add a three laser interface to into the control system?
  - Ask Jack.
11. How many electrical sockets are there?
  - Downstairs (6 spare)
  - Middle (3 spare)
  - Top (6 spare)
  - Single phase outlets in dome
  - 40A through the wrap max, or possibly >80A, supply is at the back shed for EOS, SLR runs off the main office, telescope uses little power
12. What is the power quality capable of being delivered? (Single phase, three phase, max amperage, power factor)
  - Australian Standard https://en.wikipedia.org/wiki/AS/NZS_3112
  - Some 20A outlets, cable wrap (tricky but possible to add cables), ask Jack
  - Three phase, GPOs single phase
  - Cable wrap (fancy one)
13. What is the plan regarding backup power? UPS?
  - The dome has backup power for the shutter mechanism
  - Possible to add a 15 minute UPS for the Toptica/other lasers
  - If dome loses contact
  - Heartbeating, maintaining contact, positive control
  - UPS server, if goes onto battery, TRUE flag, might lose contact to that server in power outage, last data received time: if number does not meet

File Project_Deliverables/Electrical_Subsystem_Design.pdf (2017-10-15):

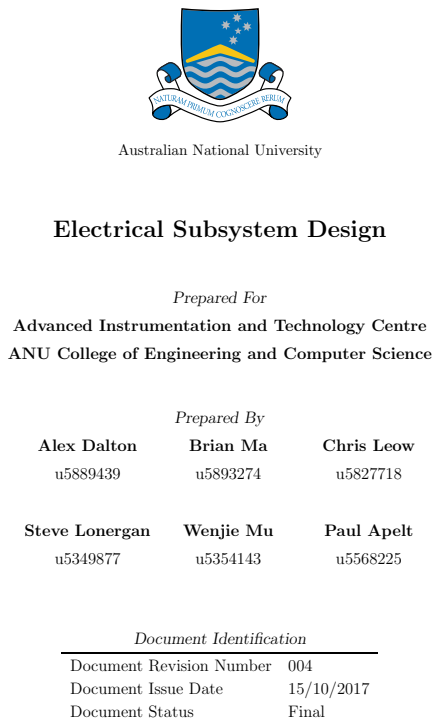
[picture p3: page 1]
Prepared For; Prepared By; Alex Dalton; Brian Ma; Chris Leow; Steve Lonergan; Wenjie Mu; Paul Apelt; Document Identification; Document Issue Date; Document Status; Final

Australian National University

Electrical Subsystem Design

Advanced Instrumentation and Technology Centre

ANU College of Engineering and Computer Science

Document Revision Number 004

## Contents

1 Introduction | 1
2 Communications | 1
2.1 Requirements | | 1
2.2 Design | | 1
3 Power | 4
3.1 Requirements | | 4
3.2 Design | | 4
4 Recommendation | 5
References | 6

## List of Tables

1 | Communication Requirements | | 1
2 | Power Requirements | | 4
3 | Power Requirements | | 4

## List of Figures

1 | Electro-Optic Systems (EOS) Auxiliary to Breadboards cables | | 2
2 | Electrical interfaces and component placement in the telescope (Horizontal view) | | 3
3 | Electrical interfaces and component placement on Level 2 of the telescope (Top view). . . . | 3
4 | All communication and power connections | | 6

i

## Acronyms

ANU Australian National University.

CAN Controller Area Network.

EC Electronics Cabinet.

EOS Electro-Optic Systems.

GSL Guide Star Laser.

LH Laser Head.

OCS Observatory Control System.

ii

## 1 Introduction

The Electrical Subsystem Design relates to the power supply and communication interfaces between the Australian National University (ANU) and EOS Guide Star Laser (GSL) Systems and the 1.8m telescope. This includes the Laser Head (LH) and Electronics Cabinet (EC) for each GSL and the chillers detailed in the Environmental Subsystem Design report [1].

## 2 Communications

Communications relates to the control interfaces between system components that allows them to interact and be controlled remotely.

### 2.1 Requirements

The requirements for the design of the communication interfaces are taken from the system subsystem document [2], and are reproduced here. These requirements are listed in Table 1.

Table 1: Communication Requirements

Reference | Description
1.4.5 2.4.1 2.4.2 2.4.3 2.4.4 | The telescope dictates that 3 free Ethernet connections to the EOS Observatory Control System (OCS) are available within the telescope. 1 on the observation deck and 2 in the electrical cabinet on the entry floor. The EOS GSL requires that one Ethernet cable be connected for engineering and maintenance [3] . The EOS GSL requires that Ethernet communication with the EOS GSL be conducted using SSH command line protocol [3] . The EOS GSL requires that Controller Area Network (CAN) bus protocol be used for control [3]. The EOS GSL requires connection to the EOS OCS for control and monitoring [3].

### 2.2 Design

An EC, called the Telescope EC in this report, is currently located on the entrance floor of the telescope, which EC relays all communication signals between the EOS OCS and the telescope. All communication signals for the EOS and ANU GSL are therefore routed through the Telescope EC.

The control for the EOS GSL is managed by an auxiliary EC through a CAN bus. This will be connected to the Telescope EC using an Ethernet to CAN gateway. This is necessary since CAN bus is not currently deployed between the OCS and the telescope.

It is recommended that the EOS auxiliary EC is situated on either the entrance level or observation of the telescope. The observation level is preferable since shorter cabling is required between EC and laser head. However, the current height of the EC (1750 mm) prevents it from being placed on the existing workbench. The proposed solution is to restructure the EC so that it is implemented as two side-by-side stacks. Alternatively, the workbench could be removed from the telescope. Situating the EC on the entrance level does not require such alterations, however longer cabling is required between the EC and laser head. It is also important to note that the EC cannot be placed on middle level since it is too large to fit through the access door, hatches, and stairwells. In this report, it is assumed that the height of the EC will not change and the EC will therefore be situated on the entrance level of the telescope. CAN bus between the EC and laser head will provide control. Specifications for the connections between the EOS EC are provided in Figure 1.

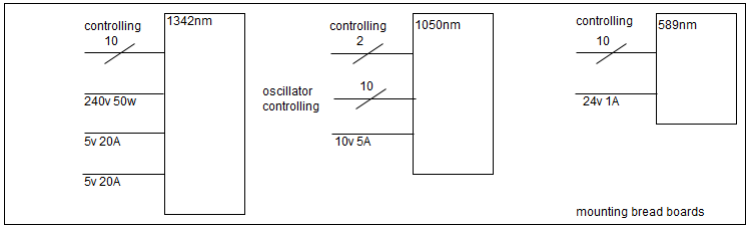
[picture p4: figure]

Figure 1: EOS Auxiliary to Breadboards cables

The control for the ANU GSL is also managed by an auxiliary EC. The EC is to be situated beneath the laser head enclosure on the observation level. This is necessary since there is a 2 m upper limit for cabling between the EC and laser head. Control of the EC can be managed by CAN bus routed from the Telescope EC via Ethernet to CAN gateway. Control of the laser head will be provided by cabling between the auxiliary EC and laser head. The type of cabling needs to be confirmed with the ANU laser vendor.

The chillers used in the recommended design are remotely controlled by serial communication [1]. The

chiller used in the EOS GSL System is to be controlled through the Telescope EC. This is necessary since control of the chiller is not supported by the EOS auxiliary EC. It is not certain whether control of the ANU chillers is supported by the ANU auxiliary EC. It is assumed that control of the ANU chillers will be provided by the Telescope EC. In this case, all three chillers will be connected to Serial lines converted from single Ethernet lines.

Figures 2 and 3 presents the electrical interfaces for the ANU and EOS GSL Systems. It should be noted that the Figures do not reflect the actual size and placement of each component.

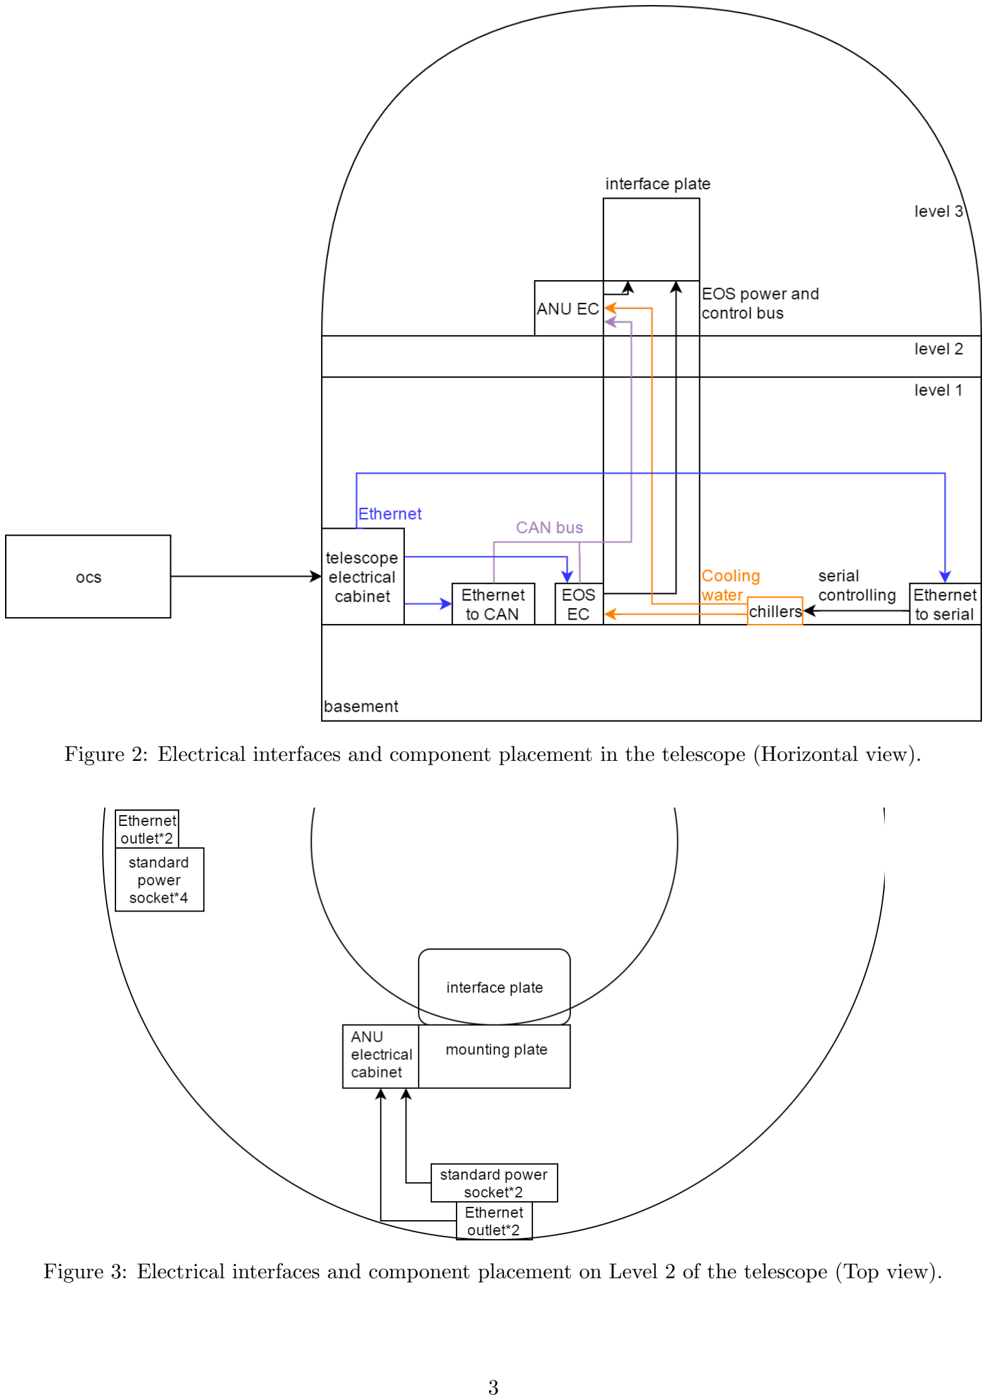
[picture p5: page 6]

Figure 2: Electrical interfaces and component placement in the telescope (Horizontal view).

Figure 3: Electrical interfaces and component placement on Level 2 of the telescope (Top view).

## 3 Power

Power relates to the supply of power to the system components.

### 3.1 Requirements

The requirements for the design of the power interface are taken from the system subsystem document [2],

and are reproduced here. These requirements are listed in Table 2.

Table 2: Power Requirements

Reference | Description
1.2.3 | The telescope dictates that the System shall require no more than 6 standard electrical plugs (240 V, 10A) on the top floor of the telescope.
1.2.5 | The telescope dictates that the System shall require no more than 8 6 standard electrical plugs on the first floor of the telescope.
2.2.1 | The EOS GSL requires 2.4kW of power via a standard single phase (230V / 10A) power socket [3].
2.2.3 | The EOS GSL requires 1 1 power plugs for chillers or oscillator. If the latter is in the clean room, 1 standard power plug for the EC in dome. [3].
3.1.5 | The telescope dictates that the ANU GSL be connected to a power supply via 1 standard power socket [4].
3.2.1 | The ANU GSL requires less than 800W of cooling [4].
3.3.1 | The ANU GSL requires approximately 800W of power for the auxiliary electrical cabinet

### 3.2 Design

The expected power draw of each system component is provided in Table 3. These details will need to be updated as additional information about both GSLs becomes available.

Table 3: Power Requirements

Source | Draw
EOS Auxiliary EC EOS Chiller ANU Auxiliary EC ANU Chiller 1 & 2 (Combined) Enclosure Environmental Control | @ 2400W @ 720W 800W @ 1680W @ 100W
Total | @ 7.8kW

The available power in the telescope is 80A, 3-phase [5], which provides approximately 32kW. The combined system draw is slightly under 25% of the available power, however the two GSLs are not

likely to be running at full power concurrently. As a result, the system will require less than the total power indicated in Table 3. This can validated further by establishing the full power draw of the active components within the dome, and ensuring that there is no possibility of exceeding the available power.

The ANU and EOS ECs and chillers, and Ethernet to CAN gateway each require 1 main power socket. Power to the EOS laser head is provided via the auxiliary EC as shown in Figure 1. Power to the ANU laser head is similarly provided by the ANU auxiliary EC, although the exact specifications need to be confirmed with the Vendor. There are sufficient power sockets currently available in telescope, indicating that the system is viable.

## 4 Recommendation

The ANU EC is to be situated on the observation level, beneath the laser head enclosure. The EOS EC, chillers, Ethernet to CAN gateway and Ethernet to serial converter are to be situated on entrance level. A summary of the electrical interfaces is presented in Figure 4. Green lines indicate power supply, magenta lines indicates Ethernet cables coming out of the Telescope EC on the entrance level, and blue lines represent CAN bus control for both ANU and EOS auxiliary ECs. It should be noted that the EOS EC also requires an additional Ethernet for engineering and maintenance. The Figure also also shows cooling water connections by yellow lines and laser path by red lines.

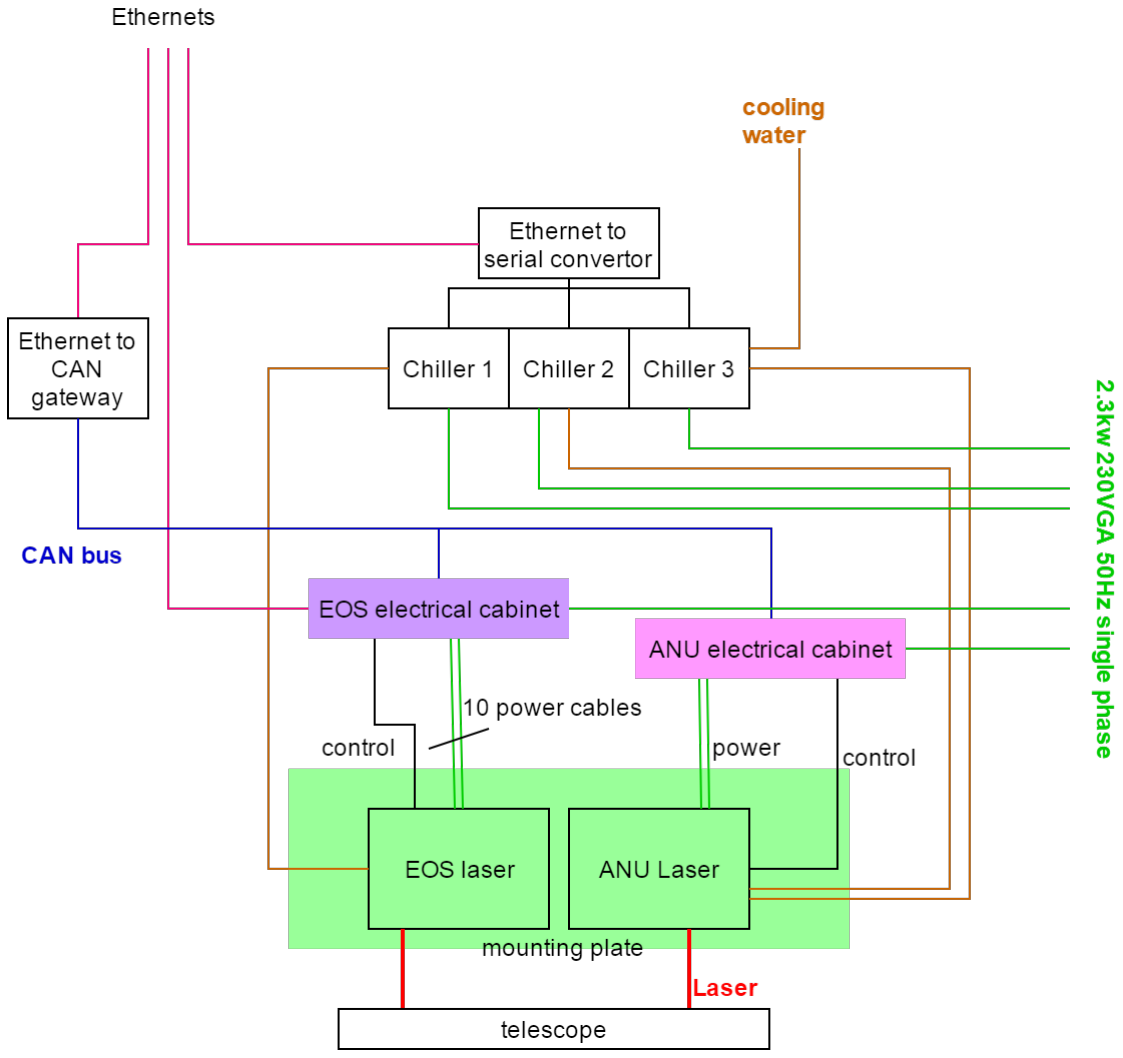
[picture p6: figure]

Figure 4: All communication and power connections

## References

[1] “Environmental subsystem design,” October 2017.
[2] “Updated system subsystem requirements,” October 2017.
[3] N. Herald, “Personal Communication 24/03/17.”
[4] C. d’Orgeville, “Personal Communication 24/03/17.”
[5] A. Gray, “Personal Communication 7/10/17.”

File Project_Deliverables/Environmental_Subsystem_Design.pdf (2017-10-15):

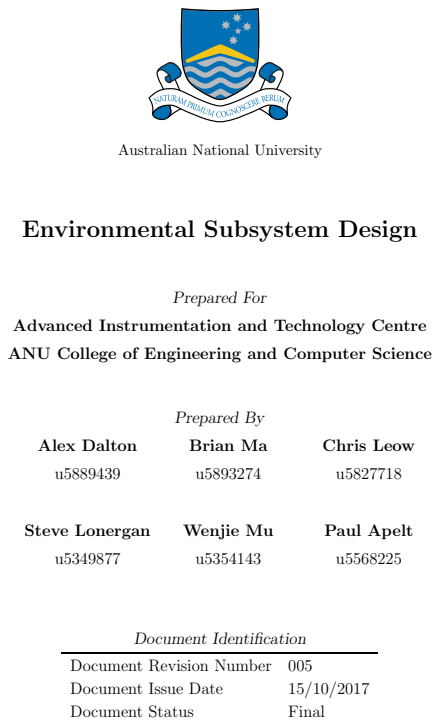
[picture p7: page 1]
Prepared For; Prepared By; Alex Dalton; Brian Ma; Chris Leow; Steve Lonergan; Wenjie Mu; Paul Apelt; Document Identification; Document Issue Date; Document Status; Final

Australian National University

Environmental Subsystem Design

Advanced Instrumentation and Technology Centre

ANU College of Engineering and Computer Science

Document Revision Number 005

## Contents

1 Introduction | 1
2 Air Quality Control Subsystem | 1
2.1 Requirements | | 1
2.2 Design Details | | 2
2.2.1 | Closed Loop System | | 2
2.3 Air Flow Requirements | | 3
3 Enclosure Temperature Control Subsystem | 3
3.1 Requirements | | 3
3.2 Enclosure Insulation | | 4
3.3 Enclosure Active Temperature Control | | 5
3.4 Hybrid Insulation and Heating | | 5
3.4.1 | Heating | | 6
3.4.2 | Cooling | | 7
3.5 System Controller | | 8
3.6 Temperature Control Design Recommendation | | 8
4 Air Intake Design Recommendations | 8
5 Component Temperature Control Subsystem | 9
5.1 Requirements | | 9
5.2 Chiller Selection | 11
5.3 Direct Cooling Design | 11
5.4 Direct Cooling Logistics | 12
5.5 Heat Exchanger Design | 13
5.6 Recommendations | 15
6 Flooring around Enclosure | 15
References | I

## List of Tables

1 | System Requirements [1] | | 1
2 | Enclosure Temperature Control Requirements [1] | | 3
3 | Heat Loss by Thickness | | 5
4 | Laser Cooling Requirements [1] | 10
5 | Laser Cooling Parameters | 10
6 | Chillers and Heat Exchangers | 11
7 | System Requirements [1] | 16

i

## List of Figures

1 | Air Intake Design | | 8
2 | Air Intake Design | | 9
3 | Design with Individual Chillers | 12
4 | Design with Heat Exchangers and First Floor Chiller | 14
5 | Design with Heat Exchangers and Main Loop | 14
6 | Anti-Static, Non-Conductive Floor Mat | 16

ii

## Acronyms

ANU Australian National University.

EOS Electro-Optic Systems.

GSL Guide Star Laser.

HEPA High-Efficiency Particulate Air.

iii

## 1 Introduction

The enclosure containing the two lasers is mounted onto the side of the telescope. It contains several components within it that produce heat, which has a direct impact on the temperature and turbulence air within the enclosure. This is partially mitigated through the usage of liquid-to-air cooling systems attached to the components, however it is not entirely removed. Additionally, the dome is not a controlled

environment due to both vents in the walls and the shutter being open during operation, meaning the environment surrounding the enclosure varies significantly. This means that the air quality within the enclosure must be controlled to ensure the propagation of the laser beams is not negatively impacted.

For these reasons, the laser enclosure is required to be a closed system, ensuring that the temperature of the various components will be controlled, as well as controlling the air quality around the laser beams. This also addresses the requirement of ensuring that the air inside the dome, specifically around the primary mirror, will be free from turbulences introduced by heated air from the system.

The following sections detail the specifics of the three subsystems, focussing on the control of air quality through filtration, the control of air temperature within the enclosure, and the cooling of laser components.

## 2 Air Quality Control Subsystem

The air quality subsystem relates to the air quality within the laser enclosure. For adequate laser propagation, the air needs to filtered to remove particulate matter, and have air flow sufficiently low so as to not introduce turbulence.

### 2.1 Requirements

The requirements for the design of the laser enclosures air quality controls are taken from the updated system subsystem document [1], and are reproduced here. These requirements are listed in table 1.

Table 1: System Requirements [1]

Reference | Description
1.5.5 1.5.2 1.5.5 2.5.5 3.2.2 | The telescope dome dictates that the System shall exist within a dirty and dusty environment. The telescope dome dictates that the System shall not produce excessive hot air turbulence within the dome The telescope dome dictates that the System shall exist within a dirty and dusty environment The Electro-Optic Systems (EOS) Guide Star Laser (GSL) requires air quality to ISO class 7 clean room standards. The Australian National University (ANU) GSL requires air quality to ISO class 7 clean room standards surrounding the laser-head

### 2.2 Design Details

To ensure that the air quality is maintained at ISO class 7 clean room standard, we utilise design components from other pre-existing systems. Testing of such a design was unable to be completed without the unit being assembled, so assumptions have been made, however these have been detailed where necessary.

The standard design for a clean room utilises positive air pressure, an area of High-Efficiency Particulate Air (HEPA) filters that the air travels through, and airflow controls to make it as laminar as possible [2]. This is necessary due to the large volume of the room, and the regular traffic that is seen inside.

On a smaller scale we see laser enclosure systems similar to this one utilising different combinations of the components. The typical arrangement is a dry-air input valve passing air through a HEPA-filter, maintaining positive pressure [3]. Due to the beadboards and the components on them causing interference

to the airflow, we do not typically see a laminar airflow, however the low air velocity and temperature uniformity mitigate this issue [4]. Additionally, due to the size and structure of the system, turbulence within the enclosure is of little concern [5].

The two possible options for the air intake are an open loop or a closed loop system. The open loop system proved to be largely inferior in design, so was removed from consideration.

### 2.2.1 Closed Loop System

The closed loop system is preferred, due to the simplicity of the system. This is due to the air being recycled, rather than needing to be vented elsewhere, requiring extensive ducting throughout the dome. By placing a HEPA filter and fan on the air intake at the top of the enclosure, with a return-air pipe at the base of the enclosure running the air back through the filter, we remove the need to constantly filter outside air.

This limits the work requirement from the filter, extending its maintenance cycle substantially. A typical filter should be replaced every 2 years, however for a filter with only a small workload, the effective life can be indefinite [6].

The closed loop system has a second advantage, in that the heating and cooling of the enclosure is easier. With the air circulating within the enclosure, the main consideration for heat exchange is through convection from the surface of the enclosure to the dome (or vice versa), and does not need to include the

heat lost or gained by taking in outside air constantly.

The single advantage that the open-loop system had over the closed-loop was by venting out air away from the dome (piping the air externally). This had the benefit of removing the heated air at a location away

from the system. The fall back of this, however, is that more heat is required to be produced, and the convection of heat from the closure is the same, regardless of the loop chosen. This was further supported by the proposed enclosure cooling design (see section 3.4.2, where the heat will be extracted with the rest

of the system heat through the chillers on the entry level.

### 2.3 Air Flow Requirements

The required air flow for good performance from a HEPA filter is approximately 0.45m~s [7, 8]. Using a

filter size of approximately 120mm 120mm, we get a flow rate of 6.48103m³

~s, or 6.48L~s.

With an enclosure volume of approximately 1.824m³
[9], we see that it takes approximately 282 seconds to

fully cycle the air within the enclosure, allowing 12 full air cycles per hour. This is approximately one third of the number of cycles that is recommended for a full size clean room to ISO Class 7 [10], however, this is likely to be sufficient for an enclosure that is mostly closed to the environment, and much smaller in size [5].

If the performance proves to be insufficient, it is recommended to include a second filter in parallel with the first, increasing the number of cycles to 24 per hour, however this is likely to be unnecessary.

## 3 Enclosure Temperature Control Subsystem

This section looks at different methods for control of the ambient air temperature within the enclosure. This is important to control due to high temperature variation, as well as temperature critical components such as the components of the cooling system that lie within the enclosure. Specific temperature control systems for individual components are detailed in section 5.

### 3.1 Requirements

The interior of the dome sees large fluctuations in temperature, due to the high seasonal variation of temperature that is seen at Mt. Stromlo, paired with relatively poor insulation on the dome. The peak interior temperature observed is 302

X

[11], and the minimum temperature is predicted to be below zero [12].

The requirements for the design of the laser enclosures temperature controls are taken from the updated system subsystem document [1], and are reproduced in table 2.

Table 2: Enclosure Temperature Control Requirements [1]

Reference | Description
1.5.3 2.5.1 3.2.3 3.2.4 | The telescope dictates that the System shall account for temperatures up to 302 XC. The EOS GSL requires ambient temperature between 0X –40XC, but could work in lower temperatures. The ANU GSL requires an operating temperature of 10X - 30XC The ANU GSL requires a non-operational temperature of greater than 5X C

The temperature requirements for the ANU GSL lies within that of the EOS GSL, so we use this as our guideline for temperature control. The required temperature during operation for the ANU GSL is between 10X

and 30XC [13], with a non-operating minimum temperature of less than 5X , without introducing
antifreeze to the cooling system [13]. Due to the recommended chillers being unable to operate with antifreeze [14], we set the minimum temperature to 10X

To maintain these temperatures, there are three proposed solutions. These are utilising insulation around the enclosure, introducing a temperature control system for the enclosure air intake, or a hybrid of the two. These are detailed in sections 3.2 to 3.4.

### 3.2 Enclosure Insulation

Using an insulating material for the side panels was one of the recommended approaches for temperature control [5]. We begin by analysing the system if insulation is not used, to determine if it is feasible to not use.

This is is dependent on which air-flow model is used. If the closed loop air control system is selected, we can find an approximate solution for the temperature by taking the heat loss through the enclosure walls. If the heat entering the enclosure from the heating element is greater than that leaving, we can conclude that this device will be able to heat the system.

One of the proposals for enclosure walls was the Kentek Blackout Windows [15], which are a polymer based

compound. These panels have a thickness of 6mm, and will have a total surface area of approximately 9.52m²
[9]. The thermal conductivity is not provided by the manufacturers, however similar materials have conductivities of between 0.15 and 0.5 W~m K. We take the higher value for this, setting it at 0.5W~m K.

Using the lowest allowable enclosure internal temperature of 10XC, and lowest enclosure external possible of 0XC, we get:

Q˙

c κA
T2 T1
L

0.5 9.52
10

0.006

7.94kW

The volume of the air within the enclosure will be approximately 1.824m³
(1.2m 1.9m 0.8m)[9]. The properties of the air within the enclosure are a specific heat of 1.004 kJ~kg K [16], and a mass of 1.275kg~m³
. This gives us a total air mass of 2.33kg. From this, we can calculate the total energy that can be lost before the enclosure has dropped to the external temperature:

Q cvmT2 T1

23.38kJ

This gives us an approximate time of 3s for the system to equalise temperature with the dome. This assumes a constant rate of convection, which will drop rapidly as the temperature differential decreases, however it is clear that a large volume of energy will be lost at a very fast rate. This is not suitable, as the power required to maintain this temperature would take over 30% of the available power in the dome [17], and would cause a large heat release around the telescope, which is to be avoided [? ]. This indicates that insulation is required.

One of the proposed insulation materials is provided by Askin [18], which offers various width panels, giving different heat loss values. Again, we used the surface area of 9.52m²
, and temperatures of 10X
internal and 0XC external.

This gives us a set of thermal loss for different thickness’s, listed in table 3.

Table 3: Heat Loss by Thickness

Thickness (mm) | Heat Loss (W)
50 75 100 125 150 175 200 | 65.66 45.34 34.62 28.00 23.50 20.24 17.80

From these values, we determine that insulation significantly reduced the heat loss from the enclosure. Unfortunately, we note that this is by no means sufficient to maintain the temperature. Repeating the same calculation as above for the temperatures to equalise, we find that the equalisation time for 50mm is slightly under 6 minutes, and slightly over 20 minutes for 200mm. As temperatures below zero would likely be maintained for several hours, we note that insulation on its own is insufficient.

### 3.3 Enclosure Active Temperature Control

Active temperature control requires both heating and cooling capabilities. The preferred method is to utilise a small heating element as part of the air intake system (detailed in section 2), as well as a liquid-air cooling unit connected the the main component chiller units (detailed in section 5).

The heating and cooling will be controlled by a simple temperature sensor and controller device, such as [19]. This will ensure adequate operation of the system.

When looking at the size of heater required if no insulation is present, we immediately see that it is impractical. 4kW of heating is required to maintain the temperature, which would require installation of 2 separate 2kW heaters inside the enclosure (this is due to the 2.4kW limitations on single phase power). A

2kW heater is sizeable, and would make the design far more complex than simply introducing insulation.

### 3.4 Hybrid Insulation and Heating

The most practical solution is that of using a small heating element, a small cooling radiator, and insulation on the laser enclosure panels.

### 3.4.1 Heating

To calculate the performance, we take values from one of the proposed devices, the Pfannenberg 10-30W heater [20]. The model used in the following analysis uses the 30W model. The surface area of the device is approximately 0.06074m²
, giving a large surface area for heat convection, and the maximum operating temperature is 140X

. The device has a duty-cycles of 100% when operating.

We note that for using the 30W model, we are able to sufficiently maintain the heat for insulation of 125mm or greater. However, due to enclosure requirement 1.1.2 limiting the overall depth of the system to 1000mm [1], it is preferable to limit the insulation width to 75mm. Using 75mm panels keeps the the

total depth at approximately 950mm, giving a larger room for error for manufacturing tolerances. To achieve the heating requirements, we include a secondary 30W heating element, which ensures heating can be achieved with the 75mm insulation, as well as including a buffer for any inaccuracies in the measurements.

It is further noted that these two heaters could be replaced by any number of heaters totalling to 60W power, provided the total surface area is equal.

To ensure that the device is capable of operating without error at maximum temperature, we must ensure that it does not exceed its maximum temperature. Using the previously calculated values, we use Newton’s Law of Cooling to calculate the surface temperature.

Q˙ C hATb Tf | (1)

where

h -

Convection Heat Transfer Coefficient

A -Surface area of device

Tb

Temperature of the surface

Tf

Temperature of the fluid

For a slow moving gas, we use the model of free convection, giving a value for h of between 10 and 20

# W~m²

K [16, 21], which could potentially be increased if needed, however it is ideal to minimise this to

both reduce air turbulence, as well as to decrease the vibrations caused by the fan.

As the device temperature will be dependent on the heat exchange with air, and that the temperature will be maintained using PID control at a minimum of 10XC, we calculate the body temperature assuming maximum supplied power. Putting these values into equation 2 for maximum and minimum h, we find:

TB,30W,min 108XC | TB,30W,max 60XC

These temperatures are all below the device maximum of 140XC, indicating that it is capable of providing the maximum rated power without issue.

From this, we determine that the hybrid system is capable of heating the enclosure sufficiently.

### 3.4.2 Cooling

To ensure that requirement 3.2.3 is achieved, active cooling is required for the entire enclosure. This can be achieved by the use of a radiator, connected to one of the coolers detailed in section 5. As the temperature requirements of all components have not yet been determined [13], the exact temperature of

the cooler it will be connected can not yet be determined.

The radiator proposed [22] does not list a surface area for the component, however due to the design of

the radiators, this will be greater than that of the heating element. The radiator has fins in a grid pattern with a spacing of less than 1mm between each fin, so by calculating the surface area for fins at a spacing of 1mm, we obtain a conservative estimate. The radiator is 120mm 120mm 40mm, giving a total of 14,400 grids. Each grid has a surface area of 40mm 1mm 1mm, giving a total surface area per grid of 40mm²

. This gives the radiator a total surface area of 2.304m²
, almost 40 times that of the heating element.

Additionally, as the cooler is 17XC, this gives a temperature differential of 13XC between the radiator and the temperature to maintain within the enclosure (30XC).

Using Netwon’s Law of Cooling, we can find the heat transfer from the enclosure into the radiator:

Q˙ C hATb Tf | (2)
10 2.304 2 | (3)
299.5W | (4)

The heat entering the system, given 75mm insulating panels with R 2.1 [18], is:

Q˙ C

# ATb Tf

R

9.52 2
2.1
9.07W

From these we can see that the radiator will be more than sufficient at removing the heat entering the enclosure, and includes a significant buffer over the anticipated maximum temperature. It also does not introduce a significant load on the coolers, as only 10W of cooling capacity is required.

### 3.5 System Controller

To ensure that the system is operating at the lowest possible workload, a PID controller may be used, such as [19]. This uses a temperature probe to monitor the internal temperature, and activates the heating

when a temperature of 5XC is detected, and the cooling system when a temperature of 30XC is detected. The heating element is a simple on-off control, however the radiator will require a valve to be shut off, restricting the flow of water. The exact radiator control method is still to be determined.

Finally, the fan may be shut off or have the fan-speed minimised when heating or cooling is not required, which will reduce the vibrations in the system.

### 3.6 Temperature Control Design Recommendation

The proposed design for the hybrid-system consists of a HEPA filter, fan, cooling radiator, and heating element in series in the air intake of the system. These are to be controlled by a PID temperature controller, which will activate the heater or cooler when the corresponding temperature limit is reached.

## 4 Air Intake Design Recommendations

The air intake system, including HEPA filter, fan, radiator, is to be in series at the top of the enclosure. The design ordering can be seen in figure 1. The arrangement is shown connected to the enclosure in figure 2¹

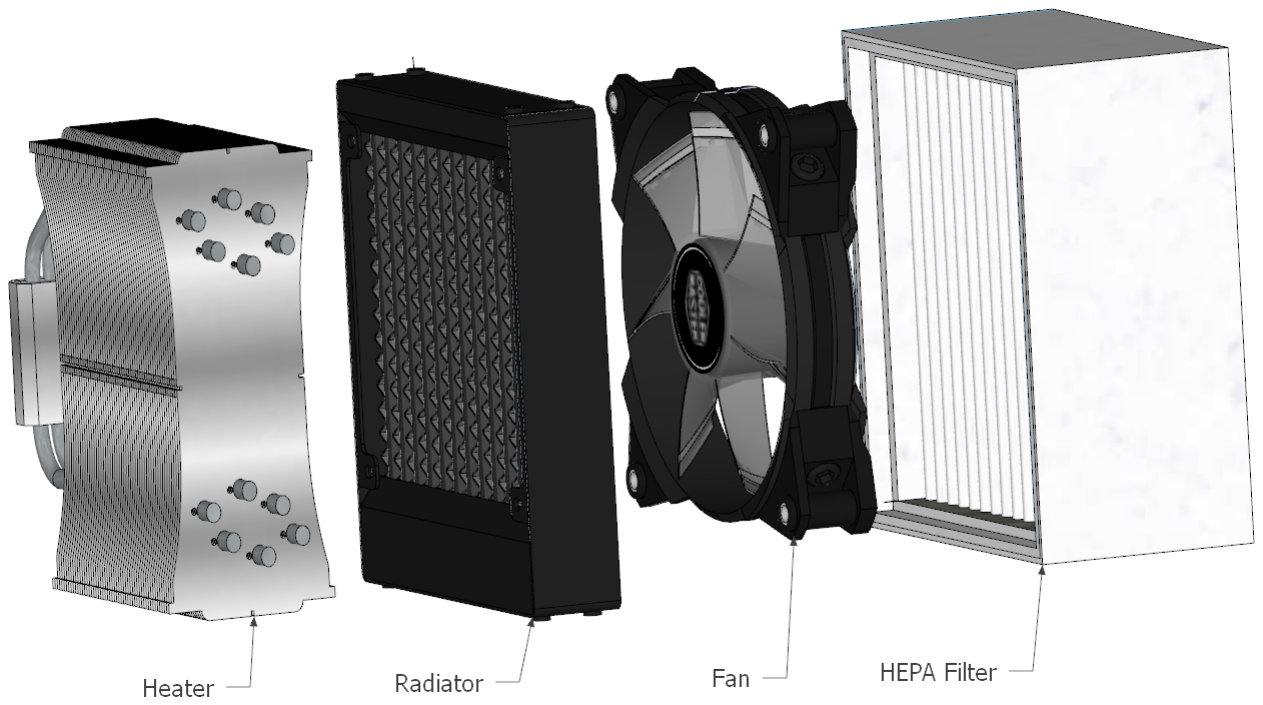
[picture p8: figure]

Figure 1: Air Intake Design

1Models sourced from https://3dwarehouse.sketchup.com/?hl=en

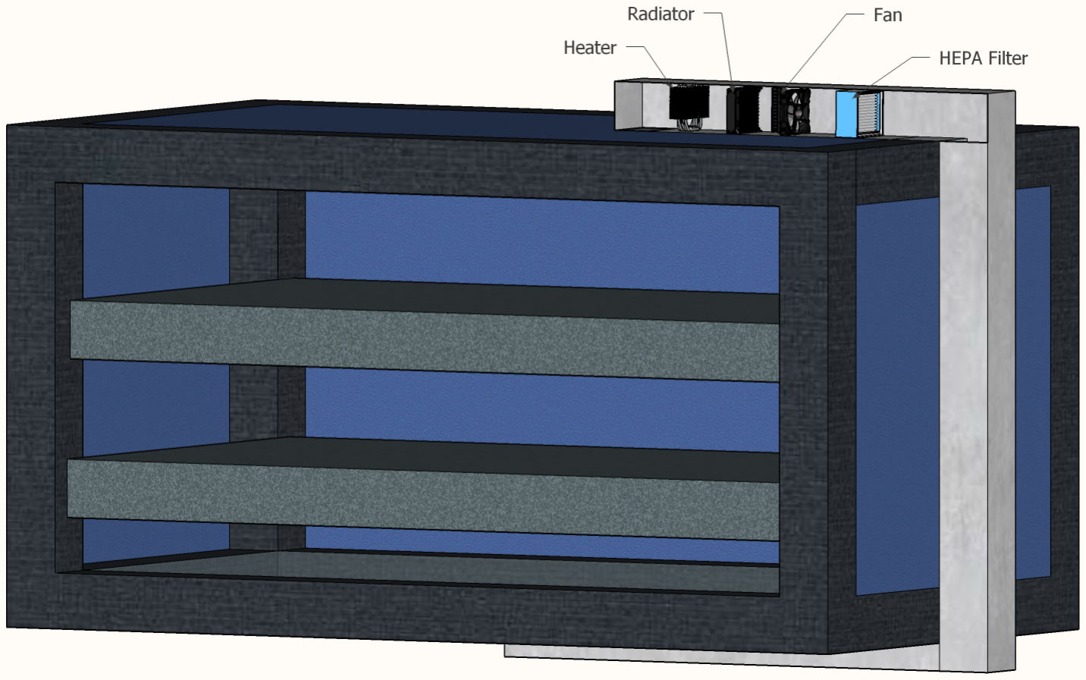
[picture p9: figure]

Figure 2: Air Intake Design

The further work required for this subsystem is to complete a vibration analysis, to ensure that the vibrations introduced by the fan will no impact the performance of either laser. This could be achieved by either limiting the fan-speed, or isolating the intake from the enclosure. The vibration tolerances for both lasers are required to complete this.

## 5 Component Temperature Control Subsystem

The EOS and ANU GSL have several components within them that require specific temperatures for operation, namely the amplifiers and oscillators. Both require continuous input of water at the specific temperatures to maintain this, through the installation of nearby chillers to extract and dispose of waste heat.

### 5.1 Requirements

The ANU GSL requires a certain volume of water at two specific temperatures for the oscillator and amplifiers, while the EOS GSL in its current state requires only one specific temperature for these components. However, due to the most likely location of the oscillators being inside the cleanroom, and the inability to route cooling pipes through the cable wrap, a fourth cooler will be required. This results in a total of three or four potential temperatures [13, 14], with four different chillers or heat exchangers required

to be installed, as each can only maintain a single temperature. However, it is likely that the oscillator components will be mounted in the clean room outside of the dome [23], which has its own cooling systems,

reducing the number of required chillers to three. In the case that the ANU laser components both require the same temperature, or the same temperature as the EOS GSL, then this number could be even further reduced. Therefore, several different cooling designs are needed, which cover all possible scenarios.

Tables 4, 5, and 6 contain the component cooling-related requirements and parameters for both lasers, taken from the updated system subsystem document [1].

Table 4: Laser Cooling Requirements [1]

Reference | Description
2.1.11 | The EOS GSL requires that 102 cooler pipes must enter the EOS GSL breadboards collectively.
2.1.12 | The EOS GSL requires The EOS GSL requires that coolers be attached to the System at a distance constrained only by the size of the telescope dome, and the vibrational impact on the lasers.
2.1.15 | The EOS GSL requires that a deionised water and OptiShield Plus solution be used as a coolant.
2.1.16 | The EOS GSL requires that any coolant additives be 100% soluble in de-ionized water.
2.1.17 | The EOS GSL requires that the cooler is re-filled with B2.8L of water as necessary.
2.5.9 | The EOS GSL requires that the amplifier components of the 1342nm laser assembly be kept at a temperature of 171 XC.
3.2.1 | The ANU GSL requires less than 800W of cooling.
3.2.5 | The ANU GSL requires a combined flow rate of 8L/min.
2.1.19 | The EOS GSL requires that Ethylene Glycol is not used in the coolers.
3.2.7 | The ANU GSL requires cooling at potentially two different temperature points, for the amplifiers and the oscillators.

Table 5: Laser Cooling Parameters

Component | Temperature | Cooling | Location | Other
EOS GSL Oscillator EOS GSL Amplifier ANU GSL Oscillator ANU GSL Amplifier | Likely 171 XC 171 XC Unknown Unknown | Combined with amplifier, B400 W, possibly as low as 30-50 W Combined with oscillator, B400 W, possibly as low as 30-50 W Combined with amplifier, B800 W. Combined with amplifier, flow of 8 L/min Combined with oscillator, B800 W. Combined with oscillator, flow of 8 L/min | Likely to be placed in the clean room, out of scope Laser enclosure, telescope third floor ANU electrical cabinet, first floor, or laser enclosure, third floor Laser enclosure, telescope third floor | OptiShield Plus solution, no ethylene glycol OptiShield Plus solution, no ethylene glycol Unknown Unknown

### 5.2 Chiller Selection

It is ideal that the chillers for the EOS GSL be able to use the OptiShield Plus solution [14], a corrosion

inhibitor which is added to the water in the cooling loop. Two different families of chillers compatible with the Optishield solution are currently being used by EOS to cool the laser in the lab, the Bayvoltex and Termotek Chillers. It was suggested that these are the most suitable to be used in the dome, due to their proven history in cooling the lasers, as well as meeting all the requirements [14, 24].

At this stage of the project, no similar requirements have been provided for the ANU laser, due to it still being in the early stage of development. It is assumed however that it will require a similar system as the EOS laser, due to the similarly delicate nature of its design, as well as for ease of installation and maintenance.

The following are the chillers and heat exchangers considered for use in the design, both those currently being used by EOS for the GSL in the lab, and other recommended models.

Table 6: Chillers and Heat Exchangers

Chiller | Cooling | Power Usage | OptiShield Compati- ble

Other Notes

Termotek P-300
Series [25]

Liquid-Liquid or Liquid-Air 10-35 degrees, 0.1 stability 300-3500 W cooling
0.5-16 l/min flow

575-2000 W 240
V Single-Phase
50 or 60 Hz
Yes | $8000+, the most ex- pensive model.

Bayvoltex
Rack-Mounted
Chiller [26]

Liquid-Liquid or Liquid-Air 5-35 degrees, 0.1 stability 500-1700 W cooling
8.3 l/min flow

720-1800 W 120
V Single-Phase
60 Hz
Yes | The | most | widely-
used | model | by
| EOS.

Bayvoltex Fluid
to Fluid Heat
Exchanger [27]

Liquid-Liquid 5-50 degrees, 0.1 stability 20,000-100,000 W cooling 8.3-37.8 l/min
flow

600-2300 W 120
or 230 V Single-Phase 60 Hz
Yes | Heat-exchanger, so
incapable of cooling
on its own and requires chilled water
| input.
Thermo Scientific Polar Series
Chiller [28]

Liquid-Air -25-80 degrees, 0.1 stability 500 W cooling 21 l/min flow

500 W 220 V
Single-Phase 50
or 60 Hz

Unknown Very low noise and vibration output, can
also heat in addition
to cooling.

### 5.3 Direct Cooling Design

One design proposed, and the preferred system by EOS, [14] is to use a similar cooling system to that

which is currently in the EOS laser lab. This is seen in figure 3. The Termotek and Bay Voltex chillers meet all of the necessary requirements, and a system with individual chillers for each is easy to implement, install, and maintain. However, it is more expensive due to having to purchase and install three individual

chillers.

The first floor of the telescope is partially insulated from the upper floors, making it an ideal place for the liquid-air chillers to be placed without affecting the air temperature of the upper floors, and causing turbulence.

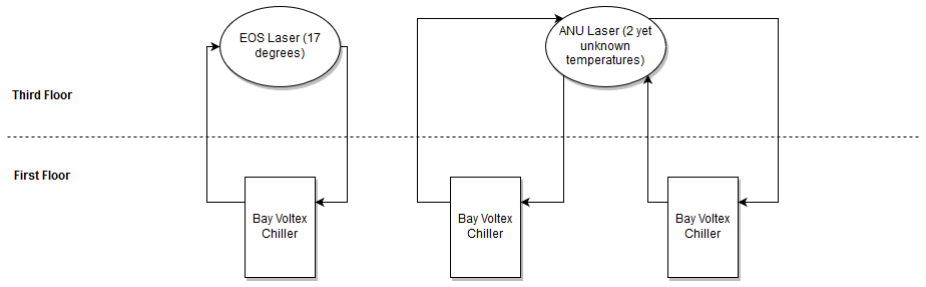
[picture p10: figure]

Figure 3: Design with Individual Chillers

Due to the fixed temperatures set in each chiller at installation, even if only one of the lasers were operated at a time, it is not possible to create a system to reuse the chillers for both lasers. The chillers that can be used for this system are the Termotek and Bay Voltex, with the appropriate thermal cooling power for each application (B400 W, B800 W), cooling solutions, and flow rate. In addition, if the final design of the

ANU or EOS lasers have very sensitive vibration or heating requirements, the Thermo Scientific Chiller

could be used instead.

The proposed design for the system is to install two MC017-19 Bay Voltex Chillers, one connected to each of the lasers, and to install one MC025-19 Bay Voltex Chiller, connected to the ANU laser; this is because the ANU laser requires a potential maximum of 800W of cooling, and the MC017-19 Chiller has a capacity of 500W; depending on the csplit between the two components the MC025-19 Chiller, with its capacity of 800W, may be necessary instead.

This is the preferred system, due to the strong thermal stability, small space requirement, minimisation of cables to be routed, and general design simplicity and flexibility. This draw back is price and the amount of chillers, however, this is a valid trade-off. EOS is currently using a wide array of chillers in the laser lab and across their other labs; if it is possible to obtain these and use them for the system, this would save significant costs and difficulty.

### 5.4 Direct Cooling Logistics

Depending on the final required cooling, the assumption in this design is that two MC017-19 Bay Voltex chillers will be required, as well as an MC025-19 chiller; other listed models are also suitable depending on new requirements. The chillers are to be installed on the first floor, in the same location as the Auxiliary Electrical Cabinet, due to it being a liquid-air system, and the first floor being partially insulted from the upper levels; if the increased air temperature from the chillers is determined not to be a problem, they could be placed on the upper level instead, significantly reducing the amount of water pipes required.

Due to relatively small dimensions (432 559 400mm each), space constraints are not a serious problem

for them. The Bay-Voltex Chillers all require 720 Watts of power and a single power socket connection each; there are six power sockets on the top floor, three on the second, and eight on the bottom. In addition, the power supply to the dome is 240 V single-phase AC; contacting the manufacturer is recommended, as they can produce chillers with different voltages and frequencies, or offer other solutions, such as converters. An RS-232 cable will be connected from each of them to the main control switch as well, in order to enable remote monitoring of the cooling operation. In addition, it will be necessary to install roughly 60 metres of water pipes along the middle of the telescope, six pipes measuring ten metres each, to connect the chillers and enable water flow to the laser components on the top floor and back.

Termotek chillers, Thermoscientific, and other models of Bay Voltex chillers are also suitable depending on any changes in requirements or new requirements for the ANU laser; if any of the individual ANU laser components requires more than 500 W of cooling, the MC025-19 BV chiller would be required instead, or if the vibration proves a serious issue, the Thermoscientific chiller is designed to solve that problem. Also, if the final design moves the EOS oscillators from the clean room to the dome, a fourth chiller would be necessary. As EOS likely has chillers available too, including those currently used for the testing of the laser, different models could be used if they are already available. The inputs to the ANU laser also might be different; it is possible that the oscillator of the ANU laser will be instead placed in an electrical cabinet, separate from the laser enclosure, requiring the cooling to be distributed there instead.

### 5.5 Heat Exchanger Design

One alternative recommendation [24] was that the design incorporate the use of Bay Voltex heat exchangers.

This was suggested because they are very reliable at maintaining a specific temperature, as well as meeting all other requirements of the cooling system.

Figure 4 is a design involving the use of three Bay Voltex Heat Exchangers to maintain individual temperatures, with a chiller on the first floor to provide the liquid cooling.

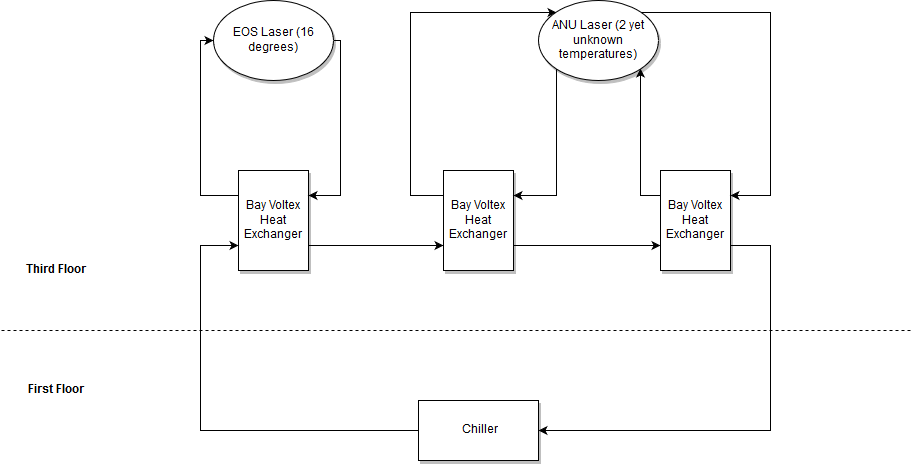
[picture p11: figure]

Figure 4: Design with Heat Exchangers and First Floor Chiller

The chiller depicted in this design could be a EXC-800 chiller (or two, if both lasers are required to operate at the same time), or any other chiller capable of providing water at a low enough temperature in a

liquid-air system.

Figure 5 is a design showing another recommended variant, this time without the chillers and instead with a connection from the observatorys main cooling loop. Note that this will require an expensive installation procedure.

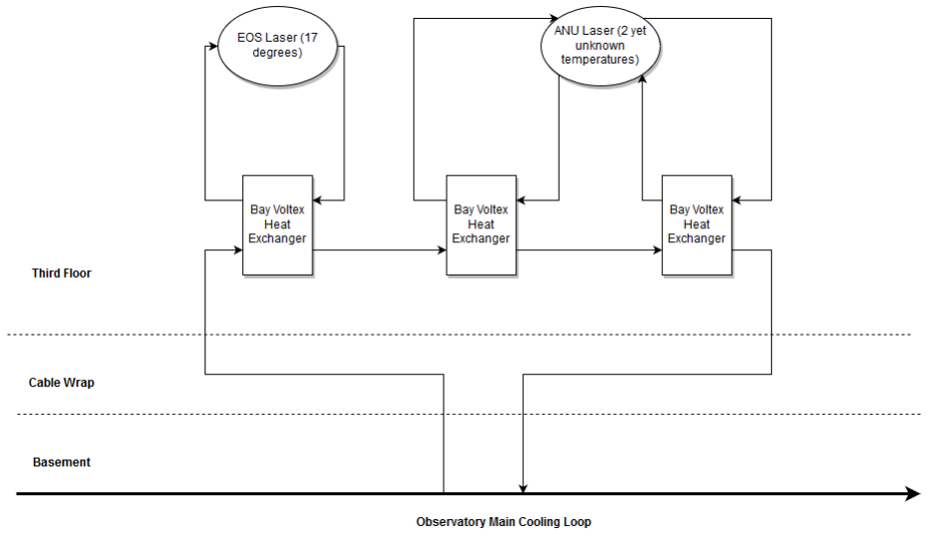
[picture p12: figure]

Figure 5: Design with Heat Exchangers and Main Loop

There are several drawbacks with this design when compared to the design above; the piping required to connect the observatorys main loop to the 1.8m telescope is likely to be both expensive and difficult to install, more so than installing a chiller on the first floor. Additionally, as the lasers are on the rotating part of the dome, they will need to have the water piped through the cable wrap, which has not been done before and will require the use of very thin pipes (between 0.25 and 0.5 inches) [24] This will significantly limit the water flow rate. However, an individual pipe should be able to provide 1kW of cooling [24], so a

single pipe should be sufficient for each component at each temperature. The low flow rate through the cable wrap is then mitigated through the use of multiple pipes.

This design should only be considered if there are other projects planned for the 1.8m telescope that are also likely to require large amounts of liquid cooling.

### 5.6 Recommendations

The current design recommendation is the direct cooling design detailed above, which uses individual chillers with their own cooling loops for each individual components that requires cooling. This is the most flexible and easily-modified and installed design, which makes it ideal for the project. This design is the easiest to adapt for requirement changes that may occur.

As more requirements become available, the design is likely change. Once the exact flow rates, cooling capacity, and temperature requirements become available, the most suitable chillers can be selected for them. It is also possible that the number of components requiring cooling, or the location of them, will change.

Future Tasks:

1. The next team should update the chiller selection if necessary based on the final cooling requirements of the lasers.
2. It is also recommended to consult with EOS to determine which chillers are available, and whether they would be willing to allow their use for the ANU GSL as well.
3. The cooling system will require different pipes for the liquid water loop, depending on the final selected design, chillers, and flow rates.
4. The control system for the cooling system has been modelled with the Bay Voltex Chillers as an RS-232 cable going to the control switch and then control centre, from which it is monitored. When a specific chiller is selected, the protocols, control method, and operating procedure for it should also be specified.
5. This design places the chillers on the insulated first floor. If the final design is updated to place them in a different location, the heat being vented in the air may need to be considered.

## 6 Flooring around Enclosure

The enclosure is required to have anti-static, non-conductive flooring surrounding it. This is to ensure no damage will occur to the components during maintenance when the enclosure walls are removed.

The requirements from the updated system subsystem document relating to this this are shown in table 7.

Table 7: System Requirements [1]

Reference | Description
2.5.6 2.5.7 | The EOS GSL requires that the area in which the System is located has an anti-static floor The EOS GSL requires that the area in which the System is located has a non-conductive floor

A mat, such as [29] will meet these requirements. To ensure that the mat covers a sufficiently large area,

the recommended size for the mat is seen in figure 6. This will ensure that nobody is able to touch the inside of the cabinet while not standing on the mat.

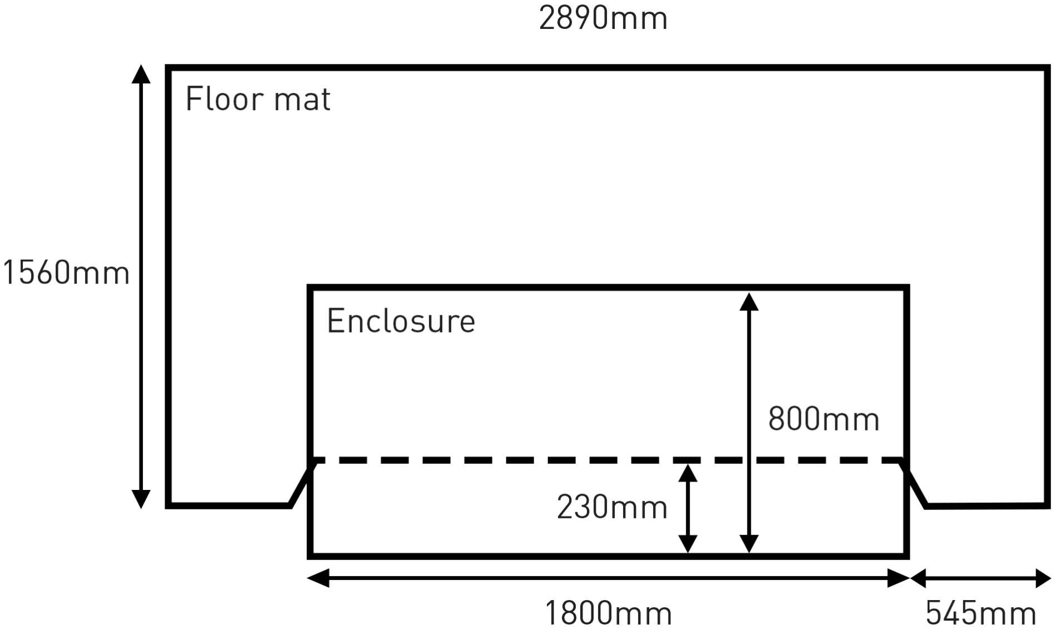
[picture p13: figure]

Figure 6: Anti-Static, Non-Conductive Floor Mat
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

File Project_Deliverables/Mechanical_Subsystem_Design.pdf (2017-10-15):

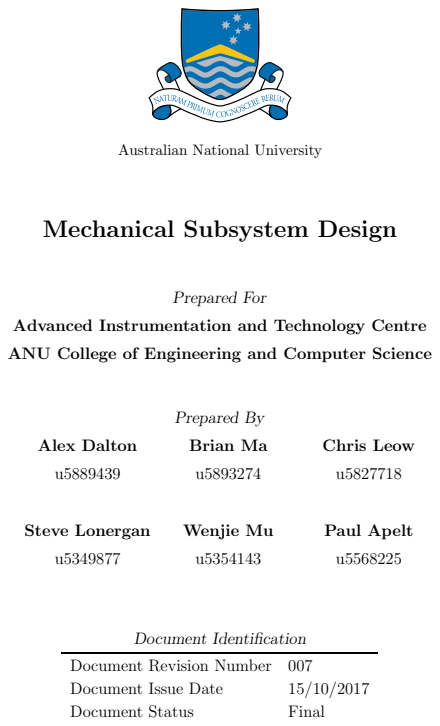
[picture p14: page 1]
Prepared For; Prepared By; Alex Dalton; Brian Ma; Chris Leow; Steve Lonergan; Wenjie Mu; Paul Apelt; Document Identification; Document Issue Date; Document Status; Final

Australian National University

Mechanical Subsystem Design

Advanced Instrumentation and Technology Centre

ANU College of Engineering and Computer Science

Document Revision Number 007

## Contents

1 Introduction | 1
2 Mounting | 1
2.1 Requirements | | 1
2.2 Concepts | | 3
2.3 Design | | 4
2.3.1 | Overview | | 4
2.3.2 | Material Selection | | 5
2.3.3 | Tubing interconnections | | 6
2.3.4 | Breadboard interface | | 7
2.3.5 | Mounting plate interface | | 8
2.4 FEA Modelling | | 8
2.4.1 | Material approximation | | 9
2.4.2 | ANSYS model | | 9
2.4.3 | Results | 10
2.5 Recommendations | 12
3 Vibration | 13
3.1 Requirements | 13
3.2 Design | 14
3.3 Testing | 14
3.4 Recommendations | 15
References | I
Appendix | II
A DragonPlate specifications | II
A.1 Carbon Fibre (CF) rectangular tube | | II
A.2 Quasi-isotropic CF angle | | II
B Isotropic approximation DragonPlate CF/epoxy composite for ANSYS modelling | IV
C Vibration testing | V
C.1 Equipment | | V
C.2 Methodology | | V

## List of Tables

1 | Mechanical System Requirements (mounting) | | 2
2 | Vibration System Requirements | 13

i
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

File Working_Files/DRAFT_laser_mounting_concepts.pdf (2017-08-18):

## Mechanical Interface Scenarios

The potential situations are as follows:
1. The EOS laser is ready first
a. EOS requires 3 breadboards
- ANU laser will be mounted on central breadboard (with BTO)
- ANU laser will be installed on site when ready (is this possible?)
- Structure supports 3 breadboards
- EOS assembled on supporting structure in lab
b. EOS requires 2 breadboards
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

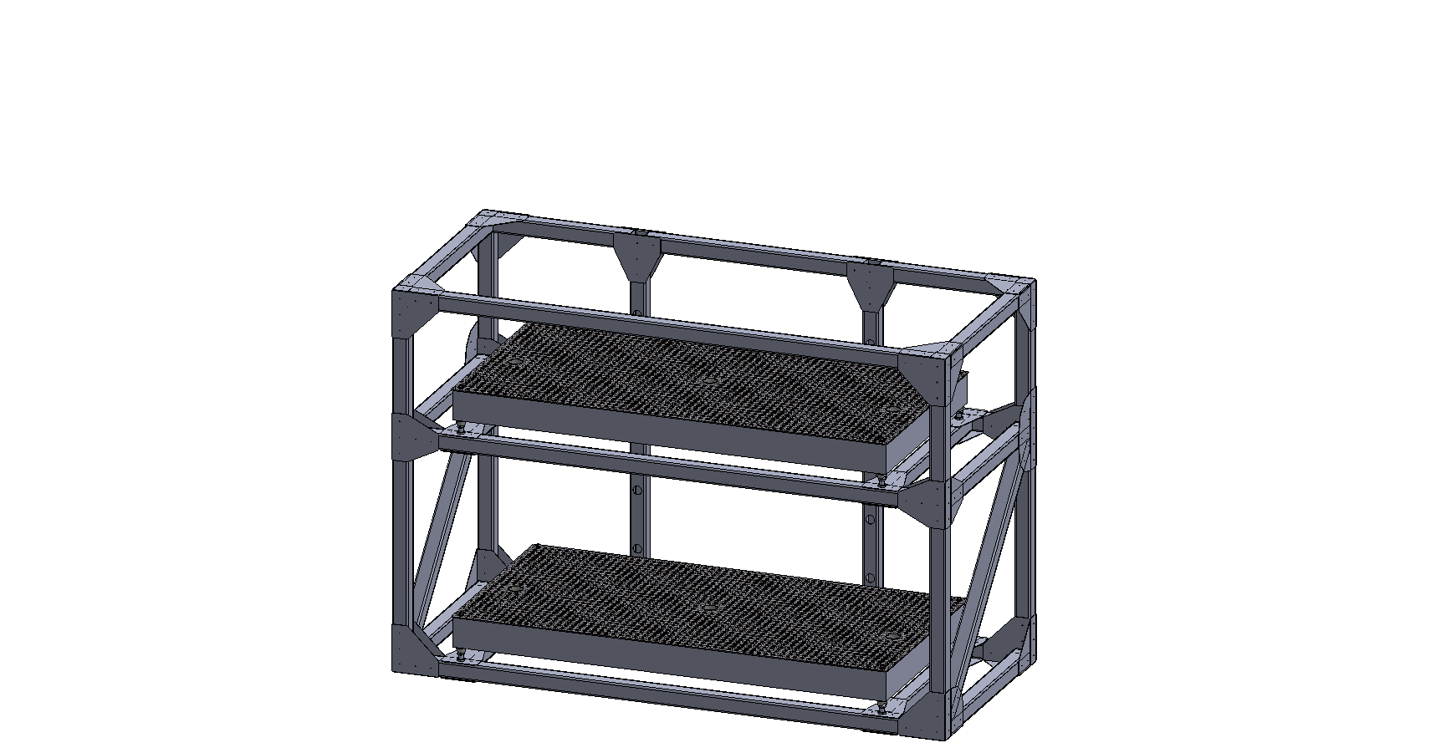
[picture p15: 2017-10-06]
Working_Files/Figures/2_tier_assesmbly_overview.PNG

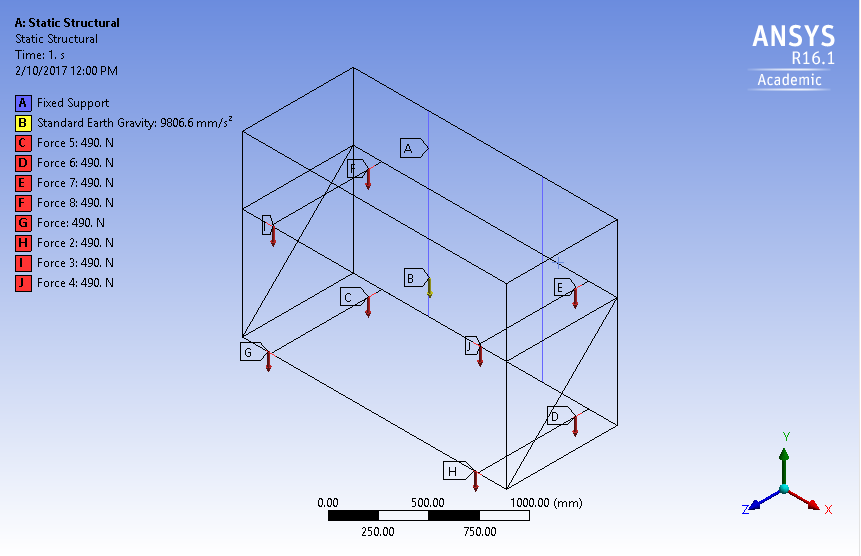
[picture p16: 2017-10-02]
Working_Files/Mechanical_Interface_Preliminary_Design/ansys_analysis/figures/model_overview.PNG

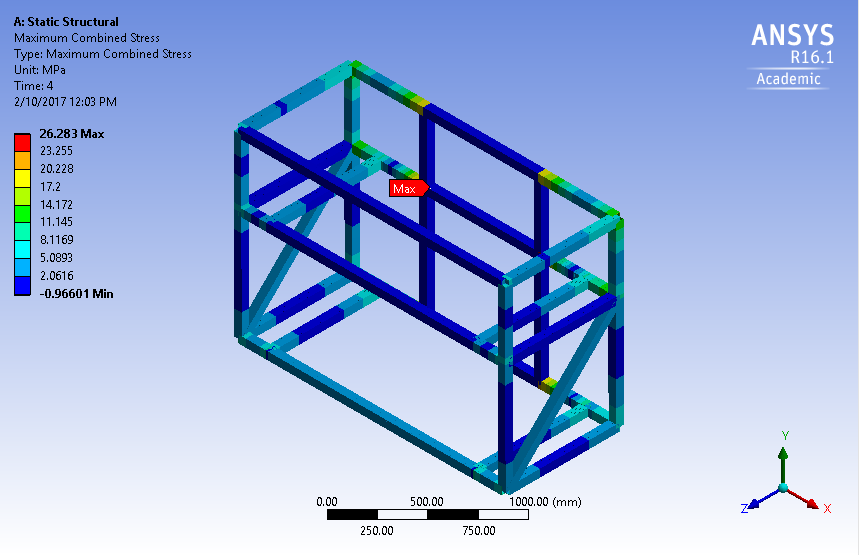
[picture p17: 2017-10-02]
Working_Files/Mechanical_Interface_Preliminary_Design/ansys_analysis/figures/max_comb_stress.PNG

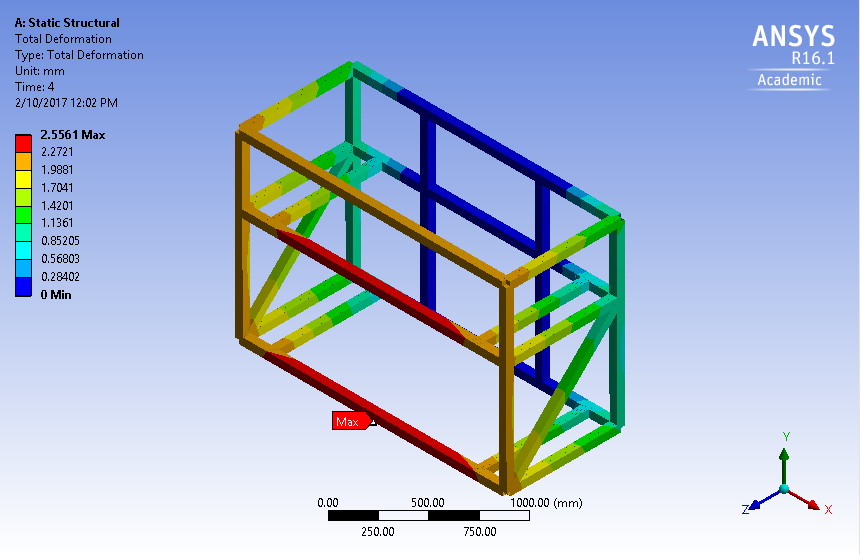
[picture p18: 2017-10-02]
Working_Files/Mechanical_Interface_Preliminary_Design/ansys_analysis/figures/deformation.PNG

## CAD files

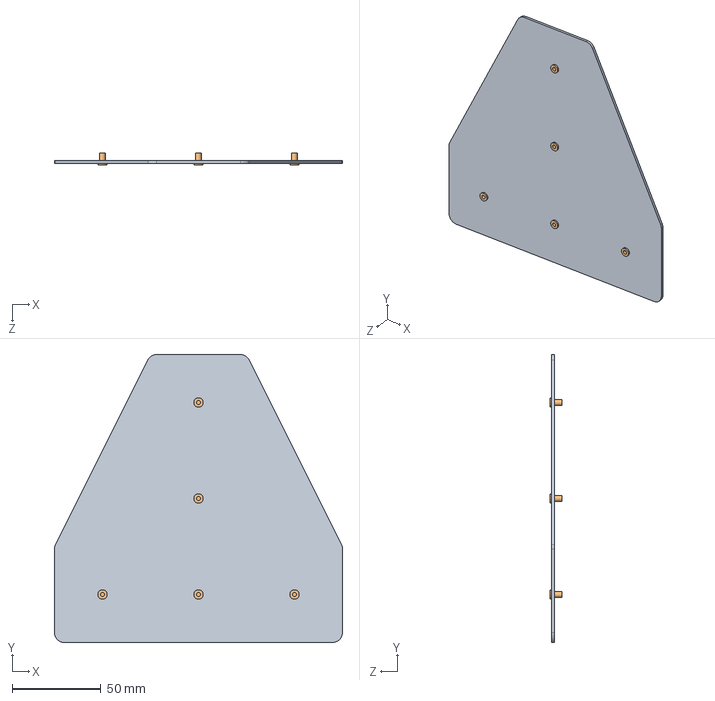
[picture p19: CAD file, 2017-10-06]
Project_Deliverables/CAD/T_w_rivets170927.SLDASM
161.9 x 161.9 x 7.00 mm
2inch_90degTee170927
0.3125 rivet170927 x 5

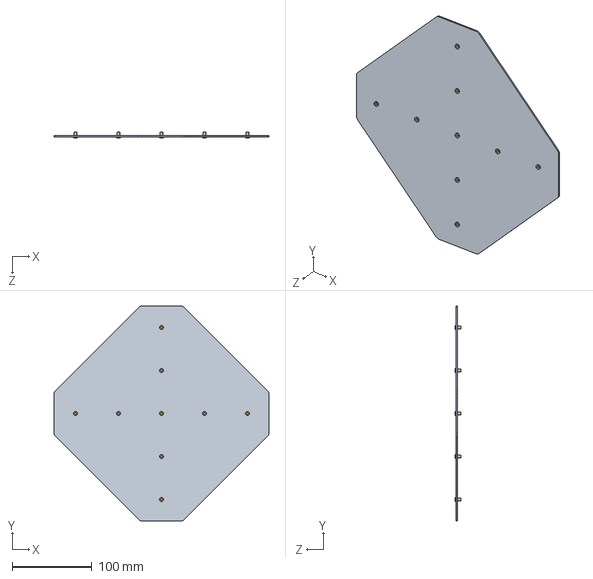
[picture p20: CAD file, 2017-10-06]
Project_Deliverables/CAD/cross_w_rivets.SLDASM
269.9 x 269.9 x 7.00 mm
2inch_plus170927
0.3125 rivet170927 x 9

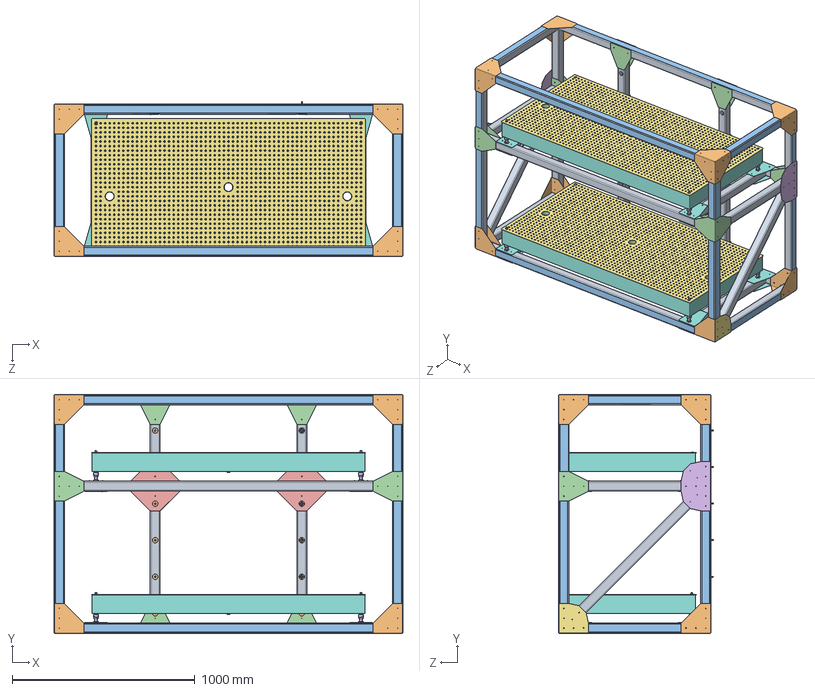
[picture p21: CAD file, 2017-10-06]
Project_Deliverables/CAD/2_tier_assesmbly.SLDASM
1909.5 x 1309.3 x 849.1 mm
DragonPlate_2_tier_frame
2inch_90degCorner170927 x 26
0.3125 rivet170927 x 224
2inch_90degTee170927 x 18
2inch_plus170927 x 4
2inch_cross170927 x 2
2inch_90degCorner_45170927 x 2
custom_T_gusset x 16
angle x 8
2_tier_inserts170927 x 2
ball_adjuster_mount x 8
m16_nut x 16
ball_adjuster x 8
Part35- ANU 2 x 2
Part36- ANU 2 x 2
Part37- ANU 2 x 12
Part39- ANU 2 x 8
Part40- ANU 2 x 3360
Part41- ANU 2 x 6
waisted shank Bolt M6 x 120- ANU 2 x 4
VB-75-SM-MODIFIED- ANU 2 x 8
socket head cap screw_ai x 10
flat washer type b regular_ai x 6

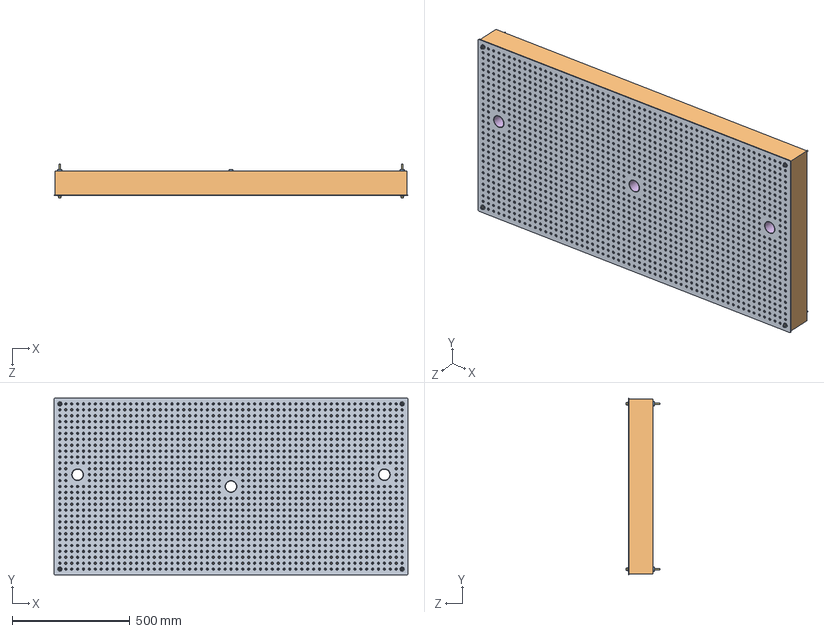
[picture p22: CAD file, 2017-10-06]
Project_Deliverables/CAD/ECI-750x1500x100-25-1-A-SP1312- ANU 2.sldasm
1500.0 x 750.0 x 146.0 mm
Part35- ANU 2
Part36- ANU 2
Part37- ANU 2 x 6
Part39- ANU 2 x 4
Part40- ANU 2 x 1680
Part41- ANU 2 x 3
waisted shank Bolt M6 x 120- ANU 2 x 4

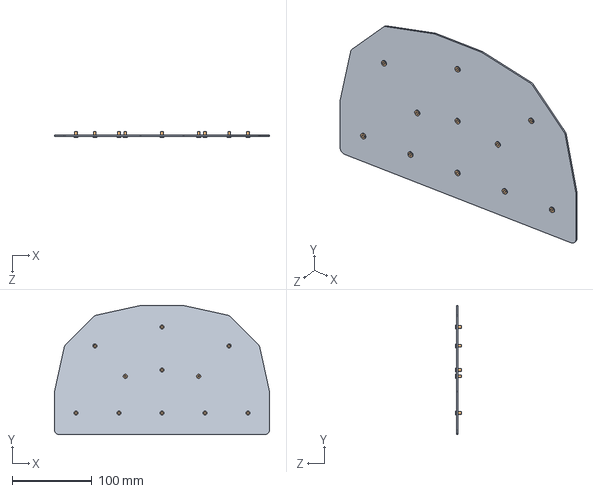
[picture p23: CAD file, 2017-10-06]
Project_Deliverables/CAD/W_w_rivets170927.SLDASM
269.9 x 161.9 x 7.00 mm
2inch_cross170927
0.3125 rivet170927 x 11

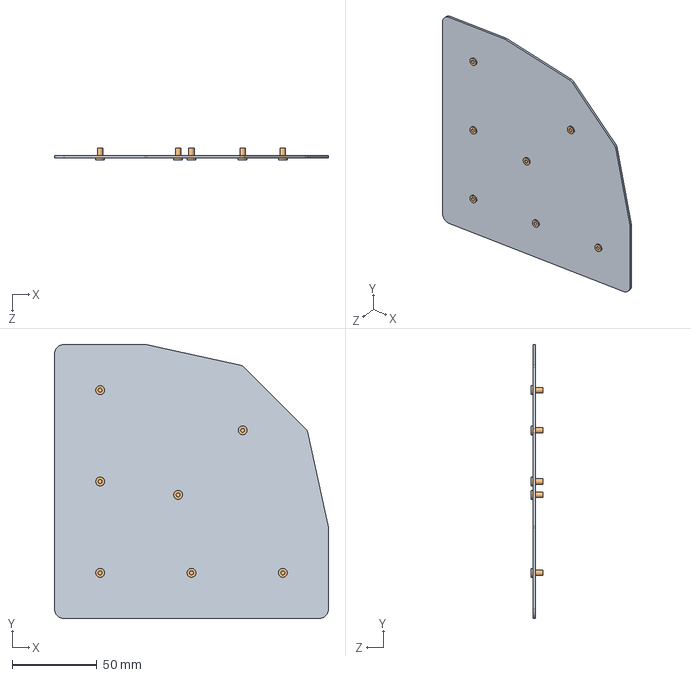
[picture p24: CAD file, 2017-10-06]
Project_Deliverables/CAD/corner_45_w_rivets170927.SLDASM
161.9 x 161.9 x 7.00 mm
2inch_90degCorner_45170927
0.3125 rivet170927 x 7

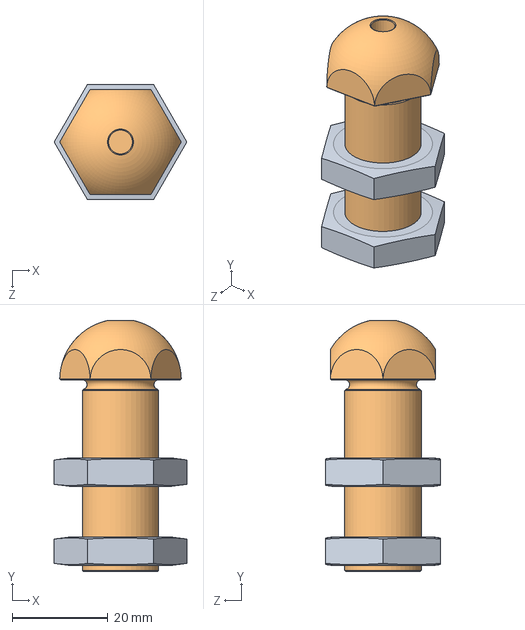
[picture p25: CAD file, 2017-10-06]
Project_Deliverables/CAD/ball_adjuster.SLDASM
27.7 x 52.4 x 24.0 mm
m16_nut x 2
ball_adjuster

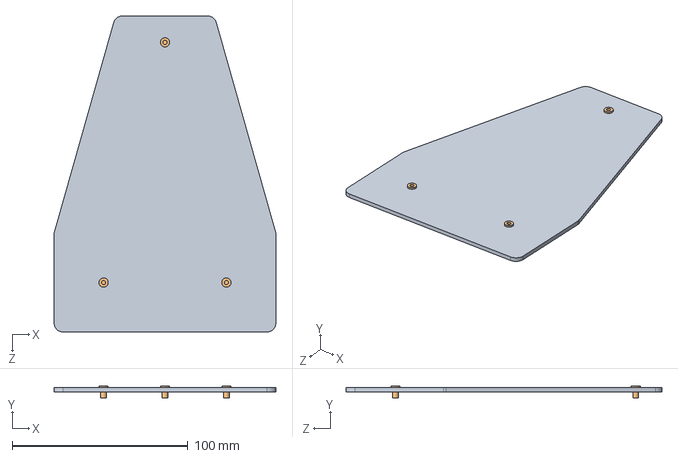
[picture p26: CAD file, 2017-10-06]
Project_Deliverables/CAD/custom_T_w_rivets.SLDASM
126.4 x 7.00 x 180.0 mm
custom_T_gusset
0.3125 rivet170927 x 3

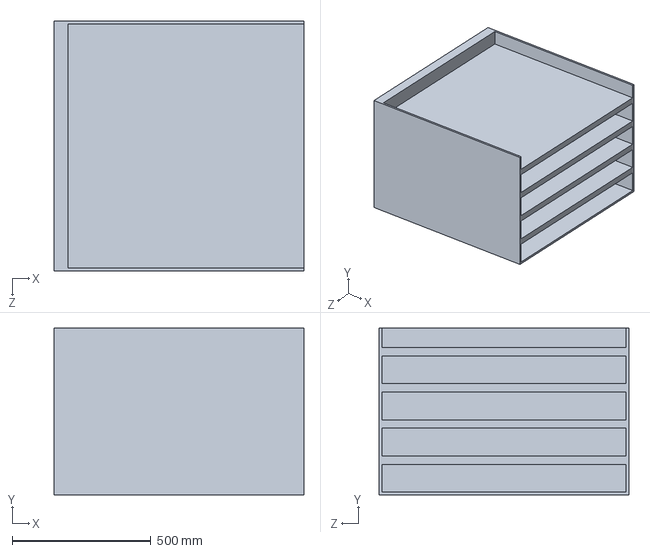
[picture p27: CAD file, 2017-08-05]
ProjectRequirements/Solution_Concepts/SolidWorks/ANU_GSL_electronics.SLDPRT
900.0 x 600.0 x 900.0 mm

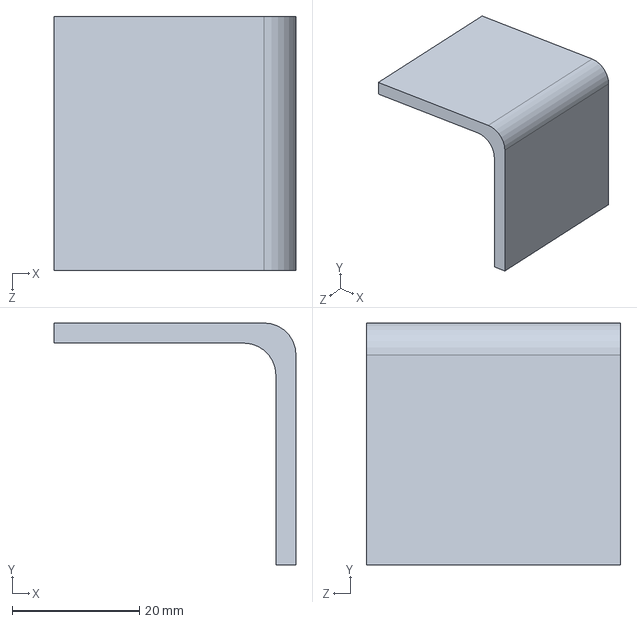
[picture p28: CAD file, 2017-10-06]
Project_Deliverables/CAD/angle.SLDPRT
38.1 x 38.1 x 40.0 mm

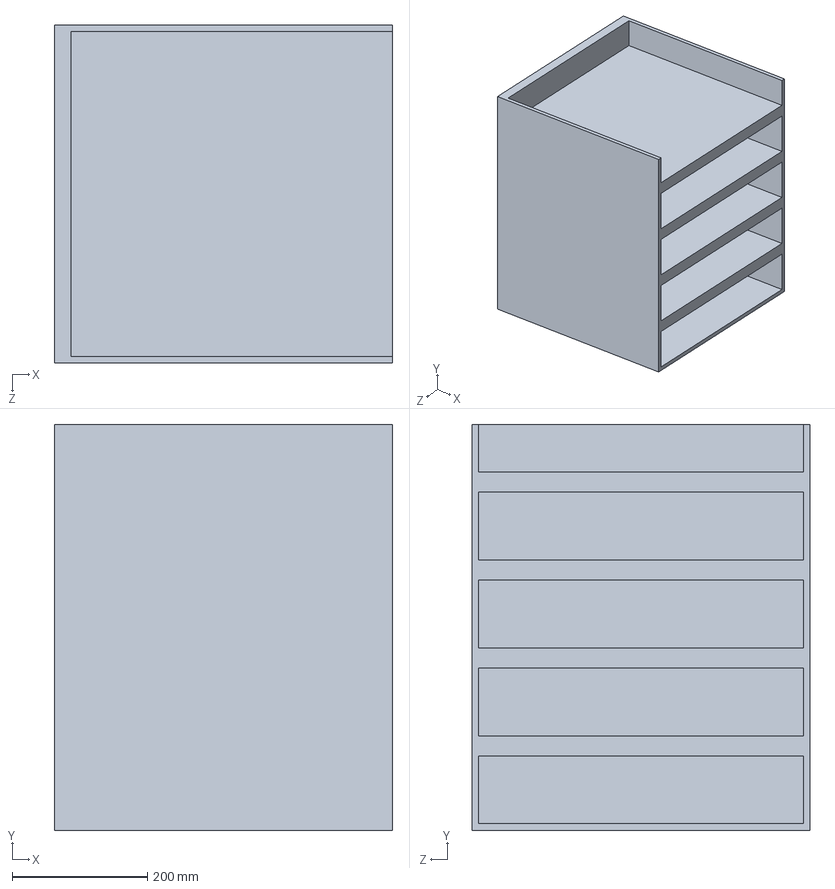
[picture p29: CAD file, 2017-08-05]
ProjectRequirements/Solution_Concepts/SolidWorks/EOS_GSL_electronics.SLDPRT
500.0 x 600.0 x 500.0 mm

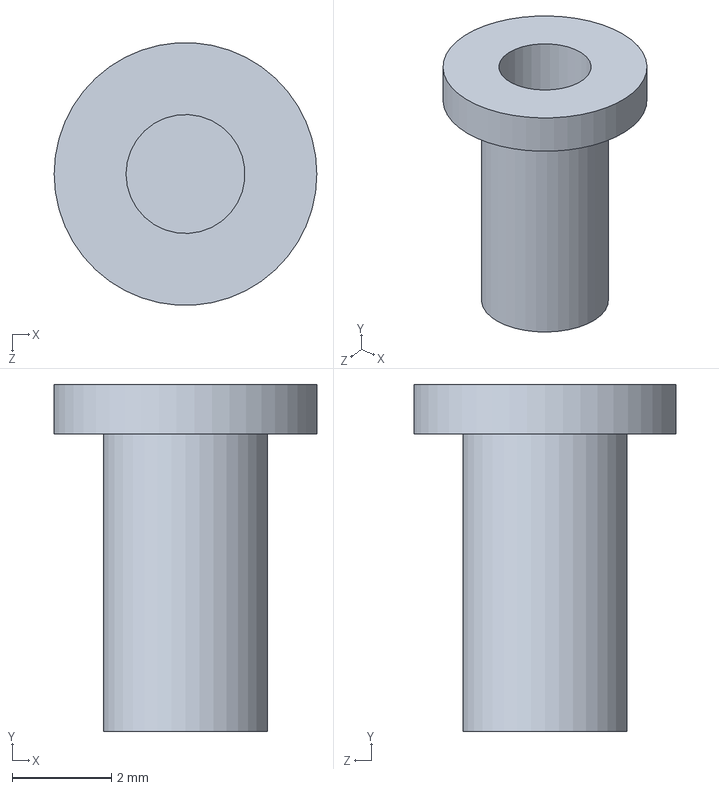
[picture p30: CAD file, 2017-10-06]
Project_Deliverables/CAD/0.3125 rivet170927.SLDPRT
5.30 x 7.00 x 5.29 mm

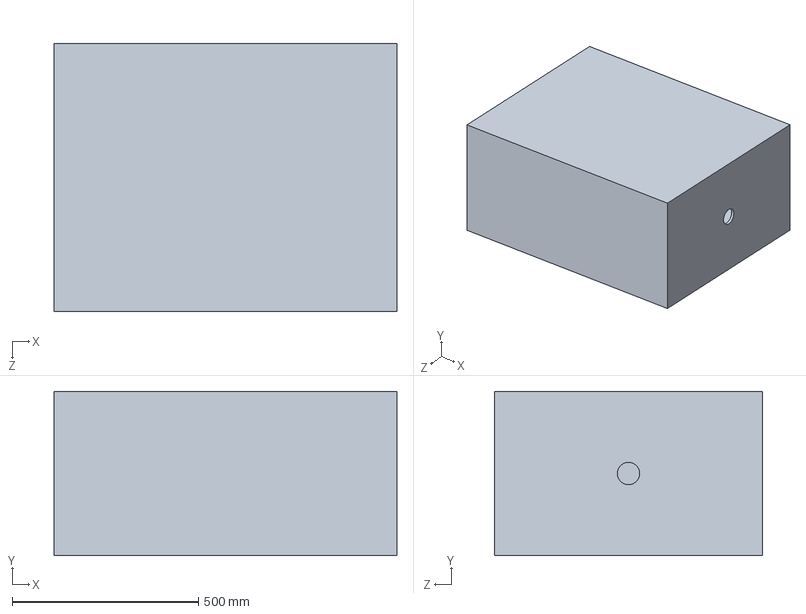
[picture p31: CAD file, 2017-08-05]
ProjectRequirements/Solution_Concepts/SolidWorks/Top_GSL_head.SLDPRT
920.0 x 440.0 x 720.0 mm

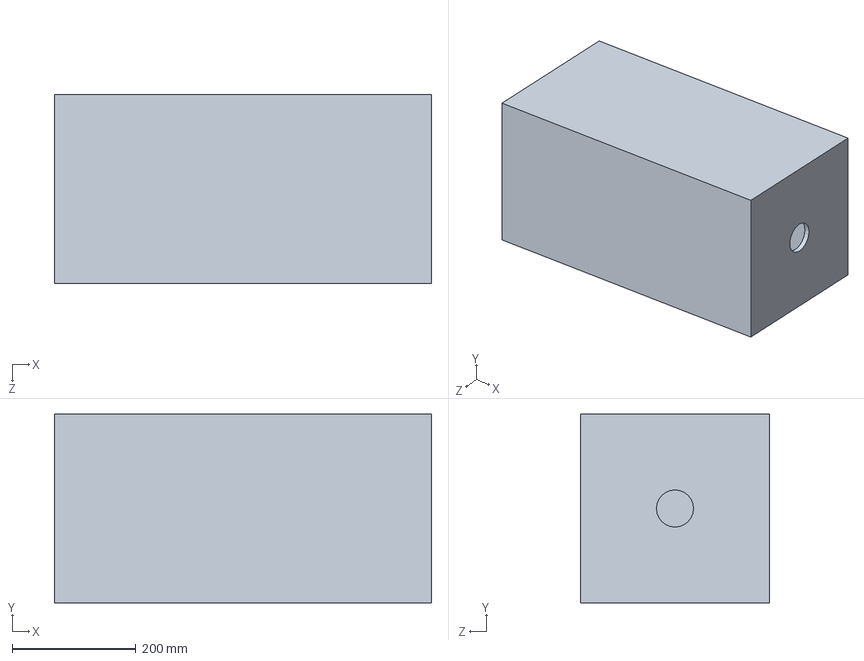
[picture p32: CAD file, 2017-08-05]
ProjectRequirements/Solution_Concepts/SolidWorks/ANU_GSL_head.SLDPRT
610.0 x 305.0 x 305.0 mm

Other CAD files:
Project_Deliverables/CAD/corner_w_rivets170927.SLDASM
Project_Deliverables/CAD/CARBONVISION CFRP BB- ANU 2.SLDASM
ProjectRequirements/Solution_Concepts/SolidWorks/Top_GSL_electronics.SLDPRT
Project_Deliverables/CAD/plasticCover.sldprt
Previous_Team_Work/Solution_Concepts/SolidWorks/Top_GSL_electronics.SLDPRT
Project_Deliverables/CAD/2_tier_inserts170927.SLDPRT
Project_Deliverables/CAD/2inch_90degCorner170927.sldprt
Project_Deliverables/CAD/2inch_90degCorner_45170927.SLDPRT
Project_Deliverables/CAD/2inch_90degTee170927.sldprt
Project_Deliverables/CAD/2inch_cross170927.SLDPRT
Project_Deliverables/CAD/2inch_plus170927.SLDPRT
Project_Deliverables/CAD/DragonPlate_2_tier_frame.SLDPRT
Project_Deliverables/CAD/Part35- ANU 2.sldprt
Project_Deliverables/CAD/Part36- ANU 2.sldprt
Project_Deliverables/CAD/Part37- ANU 2.sldprt
Project_Deliverables/CAD/Part39- ANU 2.sldprt
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

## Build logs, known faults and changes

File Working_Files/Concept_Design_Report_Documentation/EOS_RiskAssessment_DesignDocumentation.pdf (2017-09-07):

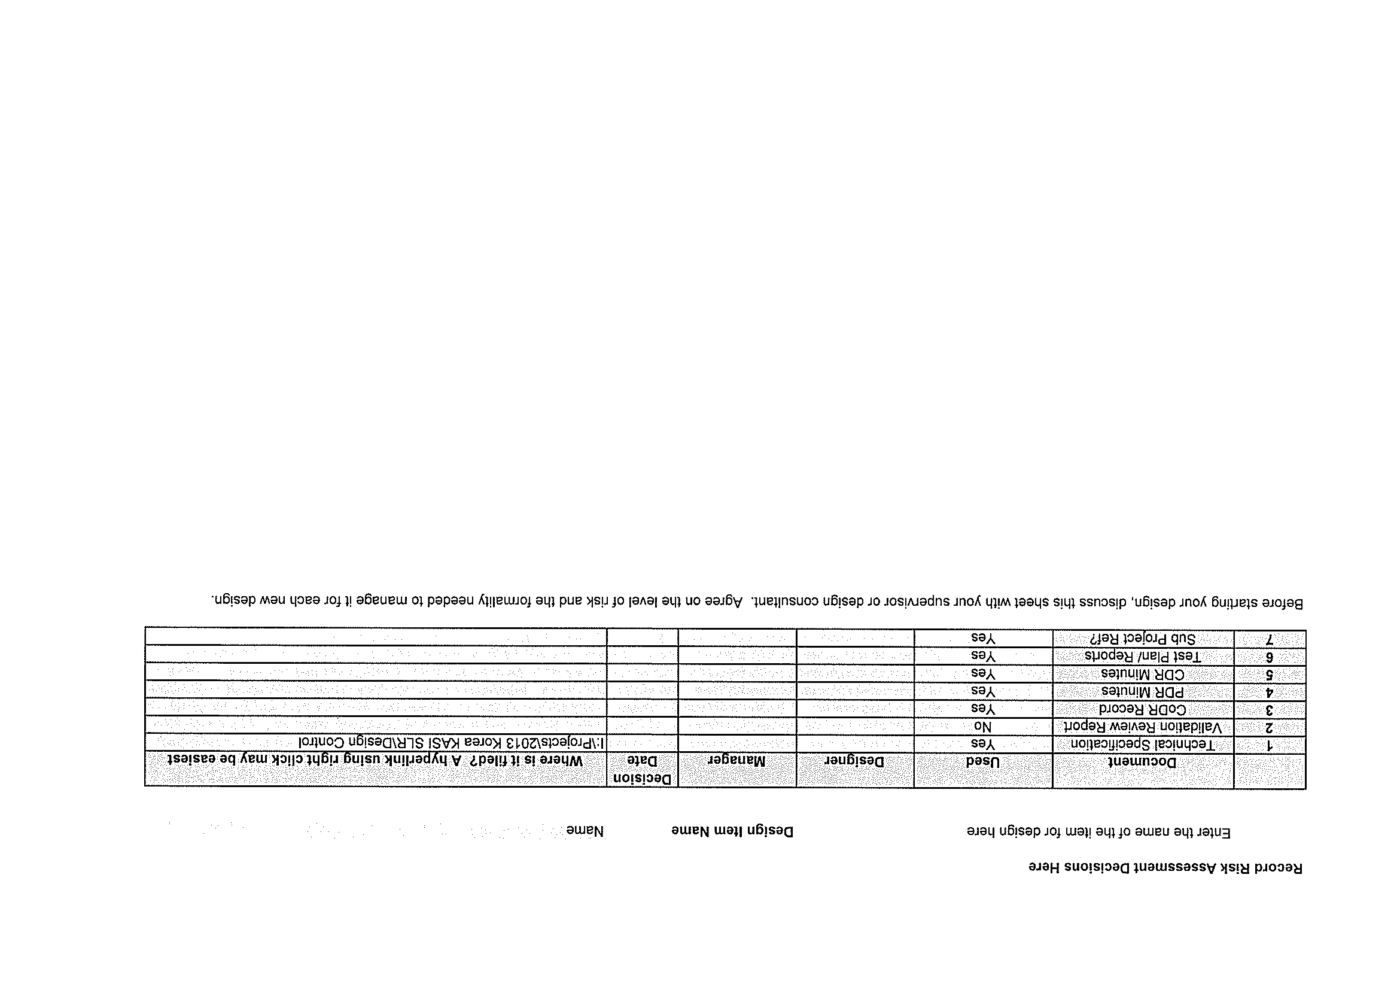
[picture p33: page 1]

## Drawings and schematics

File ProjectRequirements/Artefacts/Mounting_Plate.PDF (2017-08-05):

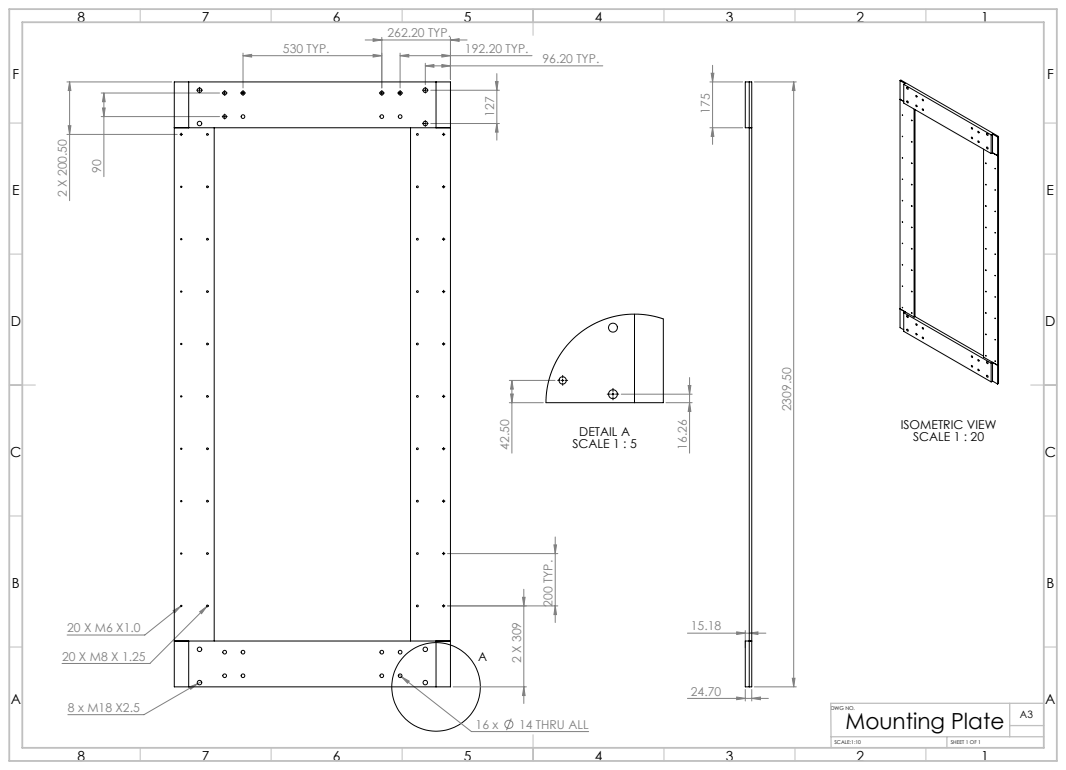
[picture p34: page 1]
14 THRU ALL; 96.20 TYP.; 192.20 TYP.; 262.20 TYP.; 530 TYP.; 200 TYP.; ISOMETRIC VIEW SCALE 1 : 20; DETAIL A SCALE 1 : 5; DWG NO.; SCALE:1:10; SHEET 1 OF 1; Mounting Plate

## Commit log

2017-08-05 Upload new file
    [Contact_list.xlsx]
2017-08-05 Renamed folders
    [ANU_GSL_electronics.SLDPRT, ANU_GSL_head.SLDPRT, Contact_list.xlsx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]
2017-08-07 Update Current_Tasks
2017-08-11 Replace activity_log.xlsx
    [activity_log.xlsx]
2017-08-14 Added Readmes, reshuffled a couple of files, and added a differentt template for activities and hours (previous groups)
2017-08-15 Commit attempt 2
    [Feedback_Action_Audit_1.xlsx, Project Hours.xlsx]
2017-08-15 Replace Feedback_Action_Audit_1.xlsx
    [Feedback_Action_Audit_1.xlsx]
2017-08-23 Summaries file update. Current_Status Directory cleaning.
    [Project Hours.xlsx, activity_log.xlsx]
2017-08-24 Fixed naming issues
    [Project_Hours.xlsx]
2017-08-24 Merged Artefacts and Requirements
    [Feedback_Action_Audit_1.xlsx]
2017-08-25 Added mounting shelf CAD
2017-08-26 Cleaned Repo for Audit. Added and removed certain files.
    [risks.xlsx]
2017-09-01 Added ANU laser team questions
2017-09-05 Unzipped solidworks
    [2_tier_frame171901.SLDPRT, CARBONVISION CFRP BB- ANU 2171901.SLDASM, ECI-750x1500x100-25-1-A-SP1312- ANU 2171901.sldasm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]
2017-09-08 Updated CAD models
    [2_tier_frame171901.SLDPRT, 2_tier_frame_doubleGussetTest170908.SLDPRT, 2_tier_inserts170908.SLDPRT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]
2017-09-08 Added cable routing
2017-09-22 Added air filtering and cabling diagrams
2017-09-28 Added laser placement drawing
2017-10-02 removed old model - final to be uploaded @ stromlo (6/10)
    [2_tier_frame_doubleGussetTest170908.SLDPRT]
2017-10-02 uploaded ansys frame model
2017-10-02 material data used in ansys analysis
2017-10-06 solidworks models
    [0.3125 rivet170927.SLDPRT, 2_tier_assesmbly.SLDASM, 2_tier_inserts170927.SLDPRT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]
2017-10-06 Updated content for enclosure (frame & environmental, not vibration), introduction and summary
2017-10-08 Documents Converted to PDFs, updated links where appropriate
    [Project_Schedule.xlsx]
2017-10-15 Reorganised folders and updated readme
    [0.3125 rivet170927.SLDPRT, 2_tier_assesmbly.SLDASM, 2_tier_inserts170927.SLDPRT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]
2017-10-15 added CAD to deliv
    [0.3125 rivet170927.SLDPRT, 2_tier_assesmbly.SLDASM, 2_tier_inserts170927.SLDPRT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]
